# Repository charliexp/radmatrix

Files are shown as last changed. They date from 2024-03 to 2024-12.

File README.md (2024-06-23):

# radmatrix

Smol modular LED matrix, consisting of 3 types of 50x50mm modules:

- LED modules with a 20x20 matrix of 0603 red LEDs
- Driver modules at the end of rows and columns (bottom and right)
- Microcontroller (RP2040) board in the bottom-right corner

This was built as my first "serious" electronics project and its main purpose was to learn electronics a bit better. Some RP2040 embedded knowledge and a blinky lights object are nice side effects.

## Results

TODO: Photos, video, PCB renders

## Design details

The LED matrix and driver module PCB design were optimized for JLCPCB Assembly - i.e. only using parts available in its (LCSC) catalog and strongly preferring Basic parts to avoid paying feeder fees. The LEDs chosen were the cheapest available in JLC's catalog (they work fine btw).

The microcontroller board was optimized for JLC PCBA to a lesser extent -- I used multiple parts that would incur a feeder fee if not for the fact that I hand-soldered them.

The display is capable of:

- 8 bit red color
- 60fps (TODO, 30fps demonstrated)

Additionally, the MCU board can:

- Read multiple "videos" (specially encoded for this firmware) from an SD card
- Pipe in 8-bit 44kHz audio
- Transmit and receive CAN messages

## v2

Now that I've leraned from my mistakes, here's what I would do if I were to build a v2 of this display (I probably won't):

- Use square, preferably RGB LED "pixels"
- Fit them in a grid of **standard** spacing (i.e. 1, 1.27, 2, or 2.54mm)
- Put pixels edge to edge
  - Current design simplfiied connections and JLC assembly, but it's ugly
- Use a black PCB for the LED matrix for increased contrast
- Move driver modules from column/row ends to the backs of LED modules
  - The current design is kinda neat, but it doesn't scale, as with each additional row of modules, the perceptual brightness of LEDs goes down
- A 2mm-spacing 32x32 standard module seems reasonable
- Connection between LED module and driver module would be done by placing 1x16 SMD pin headers alongside corners (split in half, say, bottom-left and top-right for rows, and likewise for columns to allow edge-to-edge clearance)
  - Possibly some additional pin headers for added stability, maybe some solderable nuts - some mechanical connection between modules would be nice
- Driver modules
  - Would consider constant-current drivers, although resistor-based approach seems to work fine and appeared cheaper
  - If resistor-based approach is still used, I would consider a buck converter for creating a variable LED power supply
  - Would consider not skipping any of the shift register stages as that makes programming more annoying, and in this approach, it shouldn't make layout too difficult
  - Fix v1 bugs of course
  - Would consider faster shift registers. Perhaps 74HCT (5V supply to '595 gives best performance, and HCT can handle 3v3 input), or LV*
  - Would consider a decoder instead of shift registers for selecting rows. The current method is risky in that if programming is not done correctly, multiple LED rows could be lighting up at the same time (with one resistor for multiple LEDs), overstressing them. It's likely that current approach is cheaper and requires fewer signal lines though
- Driving the display
  - Each LED/driver module would have a separate connection to the MCU board - sharing row selection, OE, SRCLK, RCLK, lines, but each having its own SER line
  - With PIO, this would have minimal impact on driving performance, and RP2040 IO counts would likely allow for 16-20 module to be connected to a single MCU board
  - This could in principle be extended further with multiple MCU boards talking to a master
  - The display would become /32, so would be brighter and that would not depend on its height
  - Each driver module should have a buffer before/after it to improve the signal

Note that while most people do projects like this with an FPGA, in my opinion the RP2040, thanks to PIO, is more than capable enough for this job at a better price, and can do other stuff in addition to just driving the display. The main downside vs an FPGA is limited IO (30 pins), which limits how big of a display can be driven. With the design above, likely ~20kpx (though this could be optimized further)

Noting the above so I don't forget or in case someone else wants to take this project further. To me, this project has fulfilled its educational goal, and making large LED displays this way is impractical given that you can get HUB75 modules for less than just the LED cost off LCSC.

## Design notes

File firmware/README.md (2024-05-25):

## convert video

automatically:

```sh
scripts/convert.sh ../badapple.webm
```

the output is in video_output

or manually:

```
ffmpeg -i ../badapple.webm -vf "fps=30,scale=40:40:force_original_aspect_ratio=increase,crop=40:40,format=gray" gfx/frame_%04d.png
```

move to `gfx` folder, then:

```
# old method
# python3 scripts/gfx_convert.py
python3 scripts/gfx_to_blob.py
```

convert audio

```
ffmpeg -i ../badapple.webm -ar 44000 audio/output.wav
```

move to `audio` folder, then:

```
python3 scripts/audio_convert.py
```

## play videos on device

create `video/YOURNAME/` folder, with files:

(where files are audio.bin, gfx.bin, gfx_len.bin)

NOTE: yourname MUST be at most 8 characters long

also `video/playlist.txt` with names of videos in order

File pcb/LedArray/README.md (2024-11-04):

# LED Matrix module

50x50mm module with 20x20 LED matrix

## Errata

### Rev A

1. I'm an idiot and somehow managed to switch polarity of LEDs. Rows were supposed to be cathodes, and columns anodes, but it's the other way around. Fixable by a 90° rotation, albeit with less than ideal trace layout. Oh well.
2. The notes about the XL-1608SURC-06 LED are incorrect, and were in fact taken from XL-1608SURC-04's data sheet. (Correction: It seems that the ealier version of XL-1608SURC-06 datasheet was incorrect). The correct info is:
   - Forward voltage: 1.9-2.3V (at 20mA)
   - Max peak forward current: 80mA
   - Max continuous forward current: 20mA

### Rev B

Sent for manufacturing 2024-11-04 (est.), delivered TBD.

Fixed orientation (with an unideal trace layout) and notes on the back.

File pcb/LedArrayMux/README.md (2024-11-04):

# LED Multiplexer

50x50mm module for driving rows and columns of LED Matrix modules

## Revisions

### Rev A

Manufactured 2024-04-06, delivered 2024-04-13.

Errata:

1. PMOS gates are pulled up to VLED (5V), while the shift register is powered from 3V3 and signals above VCC are not allowed. Ouch!
   - NMOS gates (i.e. row drivers) are not affected
   - This is not easily fixable on the board itself
   - It doesn't appear that 74HC595 dies immediately because of this, and the 10k resistor would limit worst-case scenario current to 0.5mA, but probably bad idea to ignore this altogether
   - It's possible to set VCC to 5V, and add level shifting on signal lines
   - Alternatively, the shift register could be replaced with 74HCT595 so that 3V3 signals register as logic high at 5V VCC

### Rev B

Ordered for manufacturing 2024-11-04 (est.), delivered TBD

Minor layout tweaks + added more decoupling capacitance. The major bugs are not fixed, as this rev is for a display that has it worked around.

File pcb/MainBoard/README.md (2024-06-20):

# Main Board

50x50mm microcontroller module, driving LedArrayMux modules. Contains an RP2040 microcontroller, a CAN transceiver, PWM audio output, current sensing, and level shifters to work around LedArrayMux bugs.

## Revisions

### Rev A

Errata:

1. Level shifters are too slow to be useful
  - Workaround: decrease pullup values to obnoxiously low ones (100-180Ω); do not use level shifters; increase PIO delays until functional
2. CAN receive signal is not level shifted, which exposes RP2040 to a 5V signal
  - Workaround: Do nothing; replace with a 3v3 CAN transceiver
3. The 431 shunt voltage reference does not work correctly
  - Workaround: use main 3v3 regulator for vref
4. PWM audio signal filter is suspected to be responsible for poor quality audio

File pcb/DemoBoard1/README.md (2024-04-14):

# Demo Board 1

Learning how to use shift registers, darlington arrays, and mosfets. I don't know what I'm doing.

Demo board containing LED Matrix module + some of the above components for hands-on experimentation.

Ordered 2024-03-05, manufactured, then delivered 2024-03-22.

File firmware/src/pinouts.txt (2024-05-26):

## SD breadboard connector

                  17
DAT1   GND  +3V3   CS     SHLD
  2     4     6     8     10
  1     3     5     7     9
DET   MISO   CLK   MOSI   DAT2
28     16    18     19

## Big SD card

D2  D3/CS   CMD/MOSI   VSS1 VDD CLK  VSS2  D0/MISO  D1
x    17        19       x    x   18   x      16     x

## LED drivers

- VCC
- SER
- OE
- RCLK
- SRCLK
- SRCLR

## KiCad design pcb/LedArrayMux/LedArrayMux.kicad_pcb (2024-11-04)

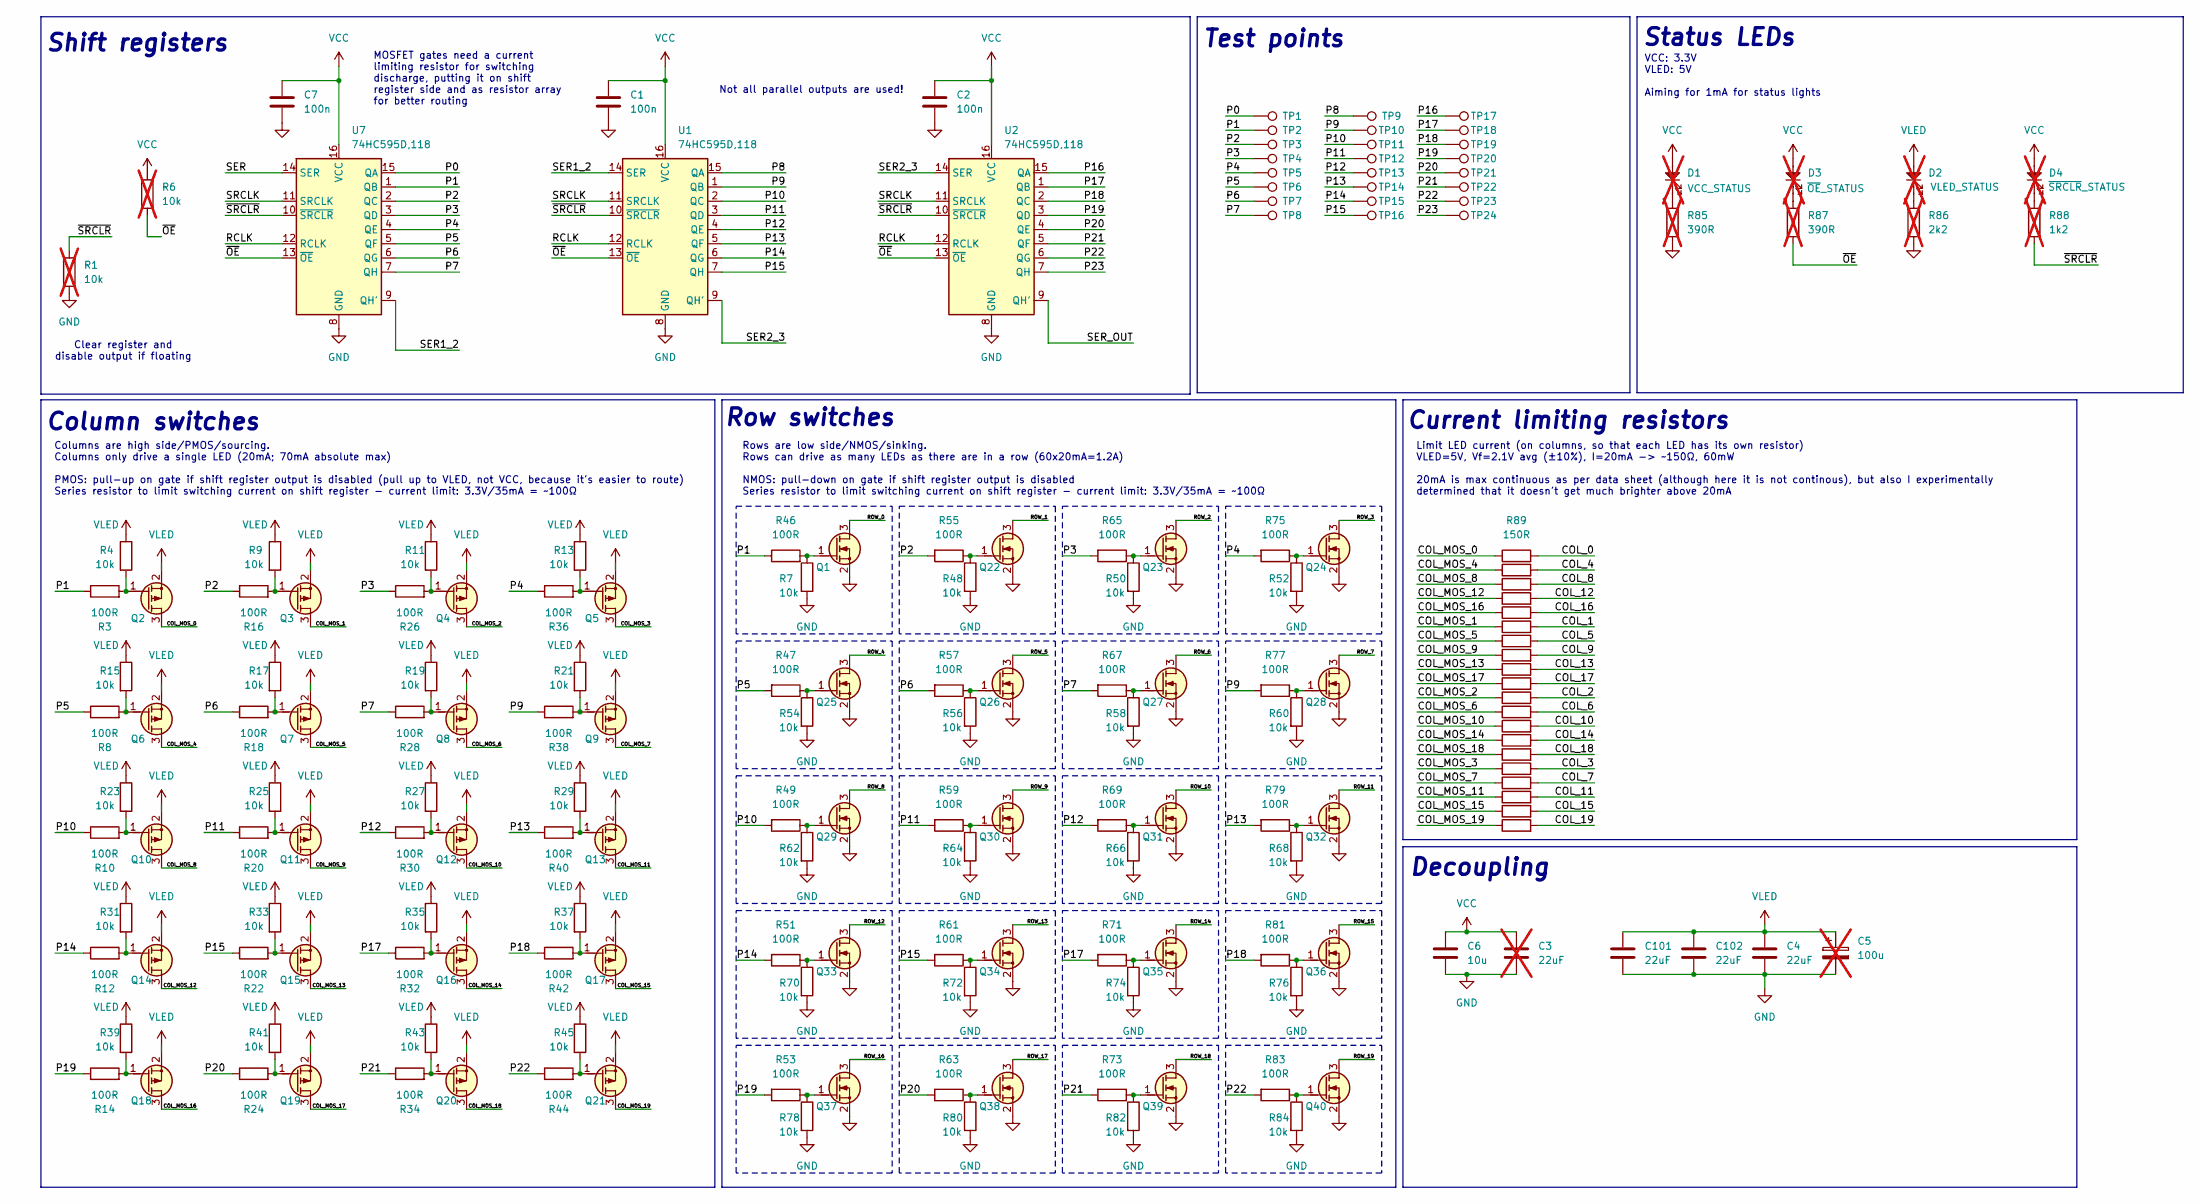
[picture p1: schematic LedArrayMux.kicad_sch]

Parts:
C1, C2, C7: 100n; R_0402_1005Metric; LCSC C307331
C3: 22uF; C_1206_3216Metric; LCSC C12891; not fitted
C4, C101, C102: 22uF; C_1206_3216Metric; LCSC C12891
C5: 100u; CP_EIA-3528-15_AVX-H; LCSC C16133; not fitted
C6: 10u; C_0603_1608Metric; LCSC C96446
D1, D2, D3: KT-0805G; LED_0805_2012Metric; LCSC C2297; not fitted
D4: KT-0805Y; LED_0805_2012Metric; LCSC C2296; not fitted
Q1, Q22, Q23, Q24, Q25, Q26, Q27, Q28, Q29, Q30, Q31, Q32, Q33, Q34, Q35, Q36, Q37, Q38, Q39, Q40: HL2304; SOT-23; LCSC C7420346
Q2, Q3, Q4, Q5, Q6, Q7, Q8, Q9, Q10, Q11, Q12, Q13, Q14, Q15, Q16, Q17, Q18, Q19, Q20, Q21: HL2301A; SOT-23; LCSC C7420344
R1, R6: 10k; R_0402_1005Metric; LCSC C25744; not fitted
R3, R8, R10, R12, R14, R16, R18, R20, R22, R24, R26, R28, R30, R32, R34, R36, R38, R40, R42, R44, R46, R47, R49, R51, R53, R55, R57, R59, R61, R63, R65, R67, R69, R71, R73, R75, R77, R79, R81, R83: 100R; R_0402_1005Metric
R4, R7, R9, R11, R13, R15, R17, R19, R21, R23, R25, R27, R29, R31, R33, R35, R37, R39, R41, R43, R45, R48, R50, R52, R54, R56, R58, R60, R62, R64, R66, R68, R70, R72, R74, R76, R78, R80, R82, R84: 10k; R_0402_1005Metric; LCSC C25744
R85, R87: 390R; R_0603_1608Metric; not fitted
R86: 2k2; R_0603_1608Metric; not fitted
R88: 1k2; R_0603_1608Metric; not fitted
R89, R90, R91, R92, R93, R94, R95, R96, R97, R98, R99, R100, R101, R102, R103, R104, R105, R106, R107, R108: 150R; R_0805_2012Metric
TP1, TP2, TP3, TP4, TP5, TP6, TP7, TP8, TP9, TP10, TP11, TP12, TP13, TP14, TP15, TP16, TP17, TP18, TP19, TP20, TP21, TP22, TP23, TP24: TestPoint; TestPoint_Pad_D1.0mm
U1, U2, U7: 74HC595D,118; SO-16_3.9x9.9mm_P1.27mm; LCSC C5947

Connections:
/COL_0: R89.2
/COL_1: R94.2
/COL_2: R99.2
/COL_3: R104.2
/COL_4: R90.2
/COL_5: R95.2
/COL_6: R100.2
/COL_7: R105.2
/COL_8: R91.2
/COL_9: R96.2
/COL_10: R101.2
/COL_11: R106.2
/COL_12: R92.2
/COL_13: R97.2
/COL_14: R102.2
/COL_15: R107.2
/COL_16: R93.2
/COL_17: R98.2
/COL_18: R103.2
/COL_19: R108.2
/COL_MOS_0: Q2.3 (D), R89.1
/COL_MOS_1: Q3.3 (D), R94.1
/COL_MOS_2: Q4.3 (D), R99.1
/COL_MOS_3: Q5.3 (D), R104.1
/COL_MOS_4: Q6.3 (D), R90.1
/COL_MOS_5: Q7.3 (D), R95.1
/COL_MOS_6: Q8.3 (D), R100.1
/COL_MOS_7: Q9.3 (D), R105.1
/COL_MOS_8: Q10.3 (D), R91.1
/COL_MOS_9: Q11.3 (D), R96.1
/COL_MOS_10: Q12.3 (D), R101.1
/COL_MOS_11: Q13.3 (D), R106.1
/COL_MOS_12: Q14.3 (D), R92.1
/COL_MOS_13: Q15.3 (D), R97.1
/COL_MOS_14: Q16.3 (D), R102.1
/COL_MOS_15: Q17.3 (D), R107.1
/COL_MOS_16: Q18.3 (D), R93.1
/COL_MOS_17: Q19.3 (D), R98.1
/COL_MOS_18: Q20.3 (D), R103.1
/COL_MOS_19: Q21.3 (D), R108.1
/P0: TP1.1, U7.15 (QA)
/P1: R3.1, R46.1, TP2.1, U7.1 (QB)
/P2: R16.1, R55.2, TP3.1, U7.2 (QC)
/P3: R26.1, R65.2, TP4.1, U7.3 (QD)
/P4: R36.1, R75.2, TP5.1, U7.4 (QE)
/P5: R8.1, R47.2, TP6.1, U7.5 (QF)
/P6: R18.1, R57.2, TP7.1, U7.6 (QG)
/P7: R28.1, R67.2, TP8.1, U7.7 (QH)
/P8: TP9.1, U1.15 (QA)
/P9: R38.1, R77.2, TP10.1, U1.1 (QB)
/P10: R10.1, R49.2, TP11.1, U1.2 (QC)
/P11: R20.1, R59.2, TP12.1, U1.3 (QD)
/P12: R30.1, R69.2, TP13.1, U1.4 (QE)
/P13: R40.1, R79.2, TP14.1, U1.5 (QF)
/P14: R12.1, R51.2, TP15.1, U1.6 (QG)
/P15: R22.1, R61.2, TP16.1, U1.7 (QH)
/P16: TP17.1, U2.15 (QA)
/P17: R32.1, R71.2, TP18.1, U2.1 (QB)
/P18: R42.1, R81.2, TP19.1, U2.2 (QC)
/P19: R14.1, R53.2, TP20.1, U2.3 (QD)
/P20: R24.1, R63.2, TP21.1, U2.4 (QE)
/P21: R34.1, R73.2, TP22.1, U2.5 (QF)
/P22: R44.1, R83.2, TP23.1, U2.6 (QG)
/P23: TP24.1, U2.7 (QH)
/RCLK: U1.12 (RCLK), U2.12 (RCLK), U7.12 (RCLK)
/ROW_0: Q1.3 (D)
/ROW_1: Q22.3 (D)
/ROW_2: Q23.3 (D)
/ROW_3: Q24.3 (D)
/ROW_4: Q25.3 (D)
/ROW_5: Q26.3 (D)
/ROW_6: Q27.3 (D)
/ROW_7: Q28.3 (D)
/ROW_8: Q29.3 (D)
/ROW_9: Q30.3 (D)
/ROW_10: Q31.3 (D)
/ROW_11: Q32.3 (D)
/ROW_12: Q33.3 (D)
/ROW_13: Q34.3 (D)
/ROW_14: Q35.3 (D)
/ROW_15: Q36.3 (D)
/ROW_16: Q37.3 (D)
/ROW_17: Q38.3 (D)
/ROW_18: Q39.3 (D)
/ROW_19: Q40.3 (D)
/SER: U7.14 (SER)
/SER1_2: U1.14 (SER), U7.9 (QH')
/SER2_3: U1.9 (QH'), U2.14 (SER)
/SER_OUT: U2.9 (QH')
/SRCLK: U1.11 (SRCLK), U2.11 (SRCLK), U7.11 (SRCLK)
/~OE: R6.2, R87.2, U1.13 (~OE), U2.13 (~OE), U7.13 (~OE)
/~SRCLR: R1.1, R88.2, U1.10 (~SRCLR), U2.10 (~SRCLR), U7.10 (~SRCLR)
GND: C1.2, C2.2, C3.2, C4.2, C5.2, C6.2, C7.2, C101.2, C102.2, Q1.2 (S), Q22.2 (S), Q23.2 (S), Q24.2 (S), Q25.2 (S), Q26.2 (S), Q27.2 (S), Q28.2 (S), Q29.2 (S), Q30.2 (S), Q31.2 (S), Q32.2 (S), Q33.2 (S), Q34.2 (S), Q35.2 (S), Q36.2 (S), Q37.2 (S), Q38.2 (S), Q39.2 (S), Q40.2 (S), R1.2, R7.2, R48.2, R50.2, R52.2, R54.2, R56.2, R58.2, R60.2, R62.2, R64.2, R66.2, R68.2, R70.2, R72.2, R74.2, R76.2, R78.2, R80.2, R82.2, R84.2, R85.2, R86.2, U1.8 (GND), U2.8 (GND), U7.8 (GND)
unnamed: D1.1, R85.1
unnamed: D2.1, R86.1
unnamed: D3.1, R87.1
unnamed: D4.1, R88.1
unnamed: Q1.1 (G), R7.1, R46.2
unnamed: Q2.1 (G), R3.2, R4.2
unnamed: Q3.1 (G), R9.2, R16.2
unnamed: Q4.1 (G), R11.2, R26.2
unnamed: Q5.1 (G), R13.2, R36.2
unnamed: Q6.1 (G), R8.2, R15.2
unnamed: Q7.1 (G), R17.2, R18.2
unnamed: Q8.1 (G), R19.2, R28.2
unnamed: Q9.1 (G), R21.2, R38.2
unnamed: Q10.1 (G), R10.2, R23.2
unnamed: Q11.1 (G), R20.2, R25.2
unnamed: Q12.1 (G), R27.2, R30.2
unnamed: Q13.1 (G), R29.2, R40.2
unnamed: Q14.1 (G), R12.2, R31.2
unnamed: Q15.1 (G), R22.2, R33.2
unnamed: Q16.1 (G), R32.2, R35.2
unnamed: Q17.1 (G), R37.2, R42.2
unnamed: Q18.1 (G), R14.2, R39.2
unnamed: Q19.1 (G), R24.2, R41.2
unnamed: Q20.1 (G), R34.2, R43.2
unnamed: Q21.1 (G), R44.2, R45.2
unnamed: Q22.1 (G), R48.1, R55.1
unnamed: Q23.1 (G), R50.1, R65.1
unnamed: Q24.1 (G), R52.1, R75.1
unnamed: Q25.1 (G), R47.1, R54.1
unnamed: Q26.1 (G), R56.1, R57.1
unnamed: Q27.1 (G), R58.1, R67.1
unnamed: Q28.1 (G), R60.1, R77.1
unnamed: Q29.1 (G), R49.1, R62.1
unnamed: Q30.1 (G), R59.1, R64.1
unnamed: Q31.1 (G), R66.1, R69.1
unnamed: Q32.1 (G), R68.1, R79.1
unnamed: Q33.1 (G), R51.1, R70.1
unnamed: Q34.1 (G), R61.1, R72.1
unnamed: Q35.1 (G), R71.1, R74.1
unnamed: Q36.1 (G), R76.1, R81.1
unnamed: Q37.1 (G), R53.1, R78.1
unnamed: Q38.1 (G), R63.1, R80.1
unnamed: Q39.1 (G), R73.1, R82.1
unnamed: Q40.1 (G), R83.1, R84.1
VCC: C1.1, C2.1, C3.1, C6.1, C7.1, D1.2, D3.2, D4.2, R6.1, U1.16 (VCC), U2.16 (VCC), U7.16 (VCC)
VLED: C4.1, C5.1, C101.1, C102.1, D2.2, Q2.2 (S), Q3.2 (S), Q4.2 (S), Q5.2 (S), Q6.2 (S), Q7.2 (S), Q8.2 (S), Q9.2 (S), Q10.2 (S), Q11.2 (S), Q12.2 (S), Q13.2 (S), Q14.2 (S), Q15.2 (S), Q16.2 (S), Q17.2 (S), Q18.2 (S), Q19.2 (S), Q20.2 (S), Q21.2 (S), R4.1, R9.1, R11.1, R13.1, R15.1, R17.1, R19.1, R21.1, R23.1, R25.1, R27.1, R29.1, R31.1, R33.1, R35.1, R37.1, R39.1, R41.1, R43.1, R45.1

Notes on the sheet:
Rows are low side/NMOS/sinking. Rows can drive as many LEDs as there are in a row (60x20mA=1.2A) NMOS: pull-down on gate if shift register output is disabled Series resistor to limit switching current on shift register - current limit: 3.3V/35mA = ~100Ω
Columns are high side/PMOS/sourcing. Columns only drive a single LED (20mA; 70mA absolute max) PMOS: pull-up on gate if shift register output is disabled (pull up to VLED, not VCC, because it's easier to route) Series resistor to limit switching current on shift register - current limit: 3.3V/35mA 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
Limit LED current (on columns, so that each LED has its own resistor) VLED=5V, Vf=2.1V avg (±10%), I=20mA -> ~150Ω, 60mW 20mA is max continuous as per data sheet (although here it is not continous), but also I experimentally determined that it doesn't get much brighter above 20mA
MOSFET gates need a current limiting resistor for switching discharge, putting it on shift register side and as resistor array for better routing
Not all parallel outputs are used!
Test points
Shift registers
Row switches
Status LEDs
Decoupling
VCC: 3.3V VLED: 5V Aiming for 1mA for status lights
Current limiting resistors
Column switches
Clear register and disable output if floating

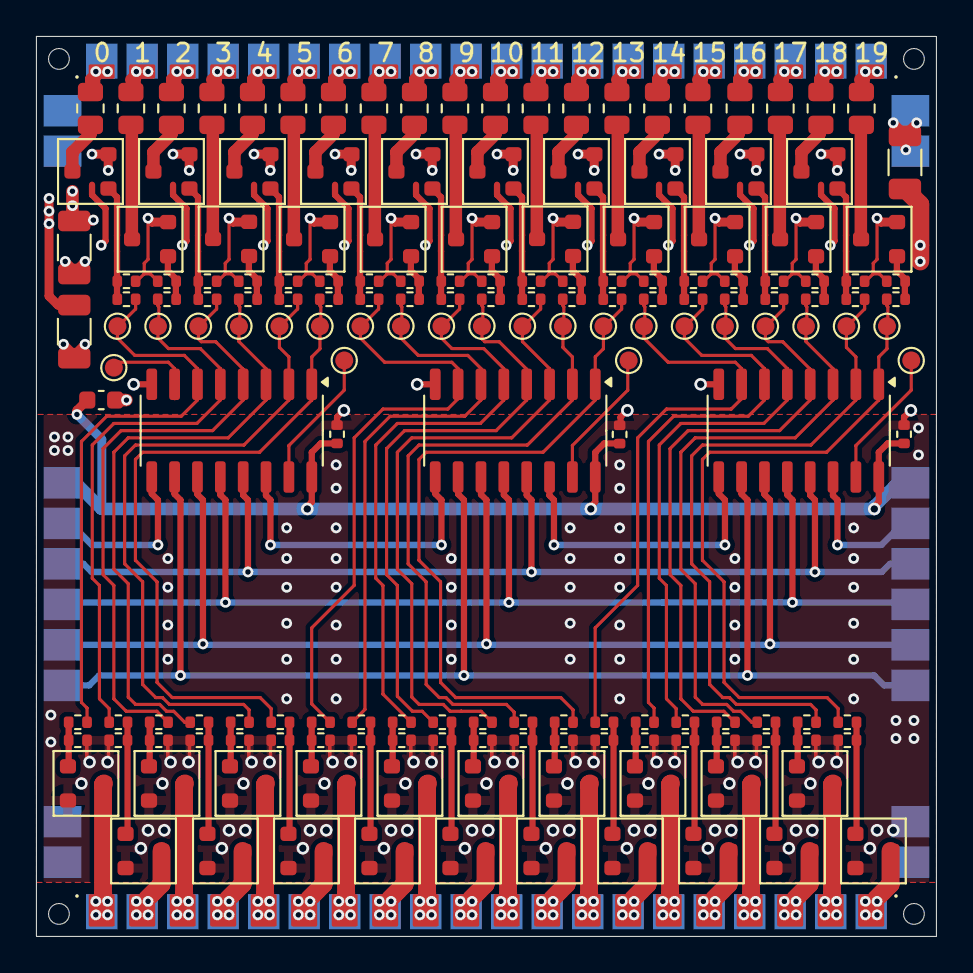
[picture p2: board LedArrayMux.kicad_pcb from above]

Board: 2 copper layers, 50.0 x 50.0 mm, 174 parts (0 on the bottom side), 93 nets.

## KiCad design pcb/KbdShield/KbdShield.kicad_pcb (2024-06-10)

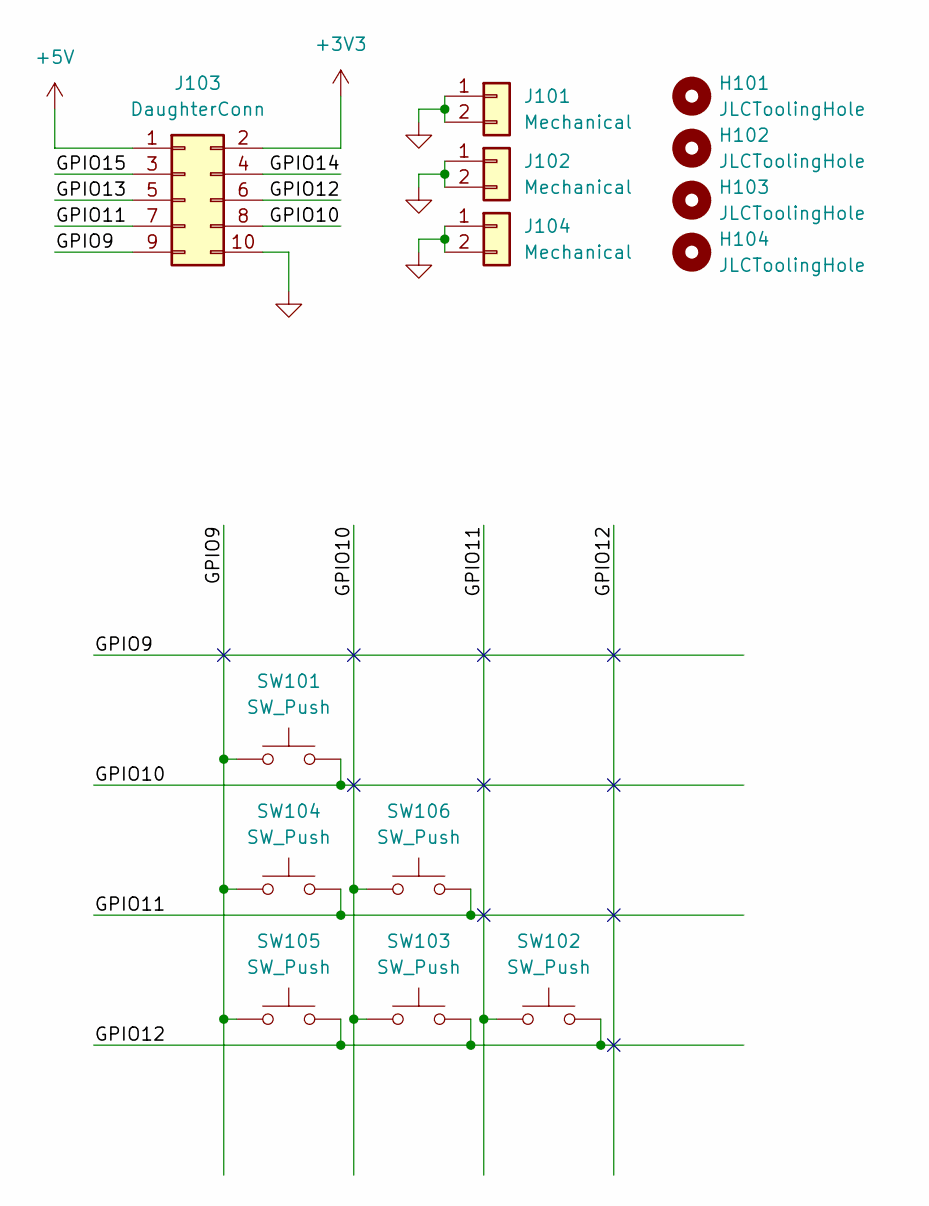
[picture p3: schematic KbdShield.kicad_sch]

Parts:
H101, H102, H103, H104: JLCToolingHole; jlcpcb-tooling-hole
J101, J102, J104: Mechanical; PinHeader_1x02_P2.54mm_Vertical
J103: DaughterConn; PinSocket_2x05_P2.54mm_Vertical
SW101, SW102, SW103, SW104, SW105, SW106: SW_Push; SW_Push_1P1T_NO_CK_KSC6xxJ

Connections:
+3V3: J103.2
+5V: J103.1
/GPIO9: J103.9, SW101.1, SW104.1, SW105.1
/GPIO10: J103.8, SW101.2, SW103.1, SW106.1
/GPIO11: J103.7, SW102.1, SW104.2, SW106.2
/GPIO12: J103.6, SW102.2, SW103.2, SW105.2
/GPIO13: J103.5
/GPIO14: J103.4
/GPIO15: J103.3
GND: J101.1, J101.2, J102.1, J102.2, J103.10, J104.1, J104.2

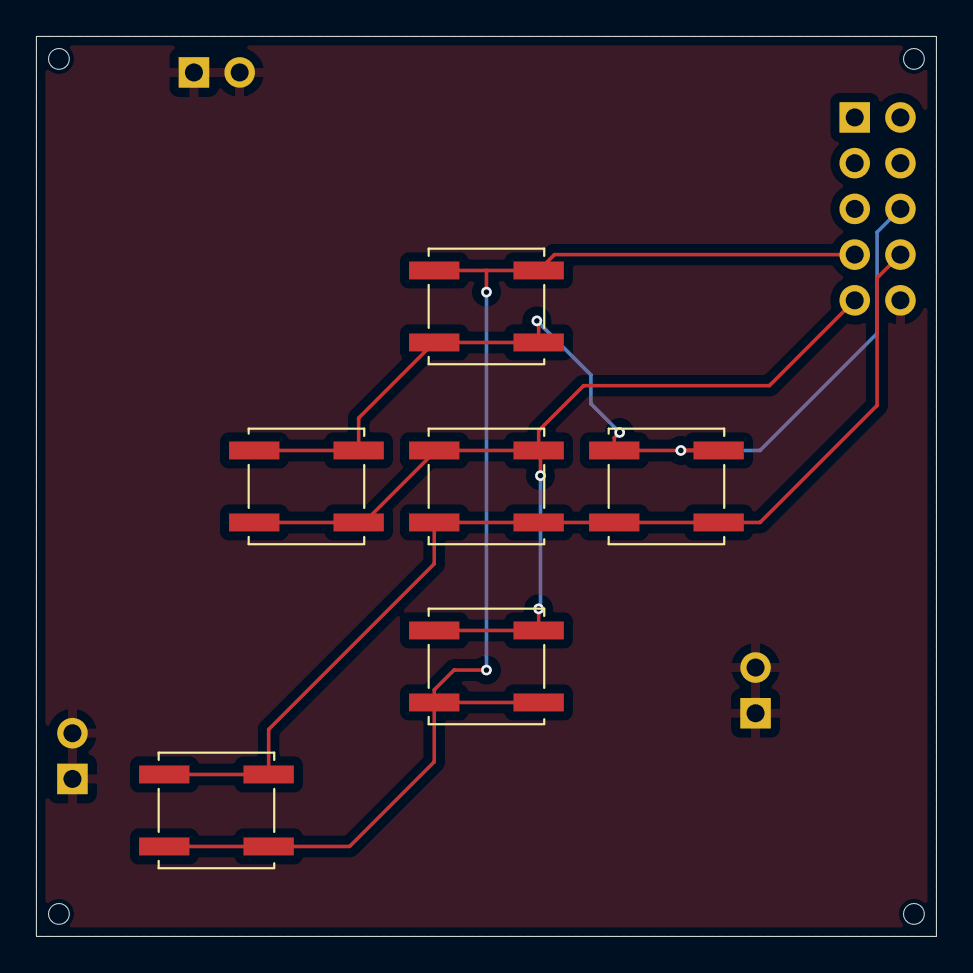
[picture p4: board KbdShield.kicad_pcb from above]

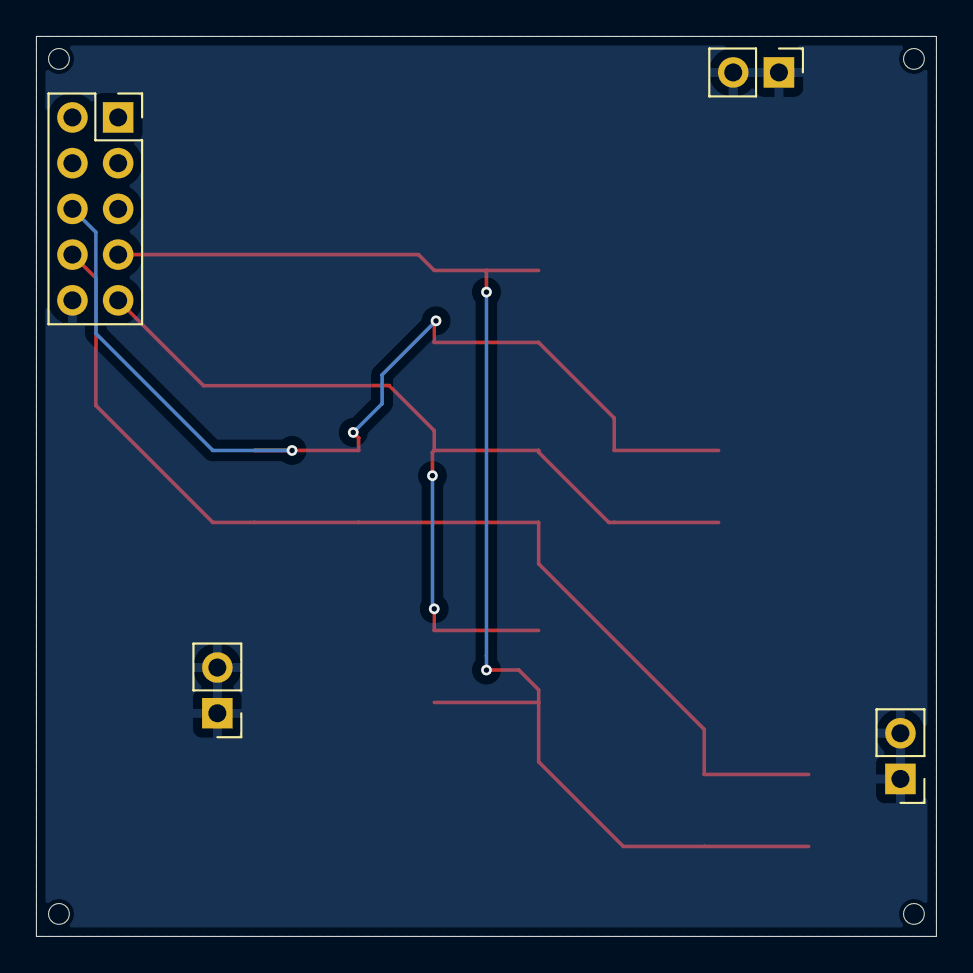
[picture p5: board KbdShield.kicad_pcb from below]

Board: 2 copper layers, 50.0 x 50.0 mm, 14 parts (4 on the bottom side), 5 nets.

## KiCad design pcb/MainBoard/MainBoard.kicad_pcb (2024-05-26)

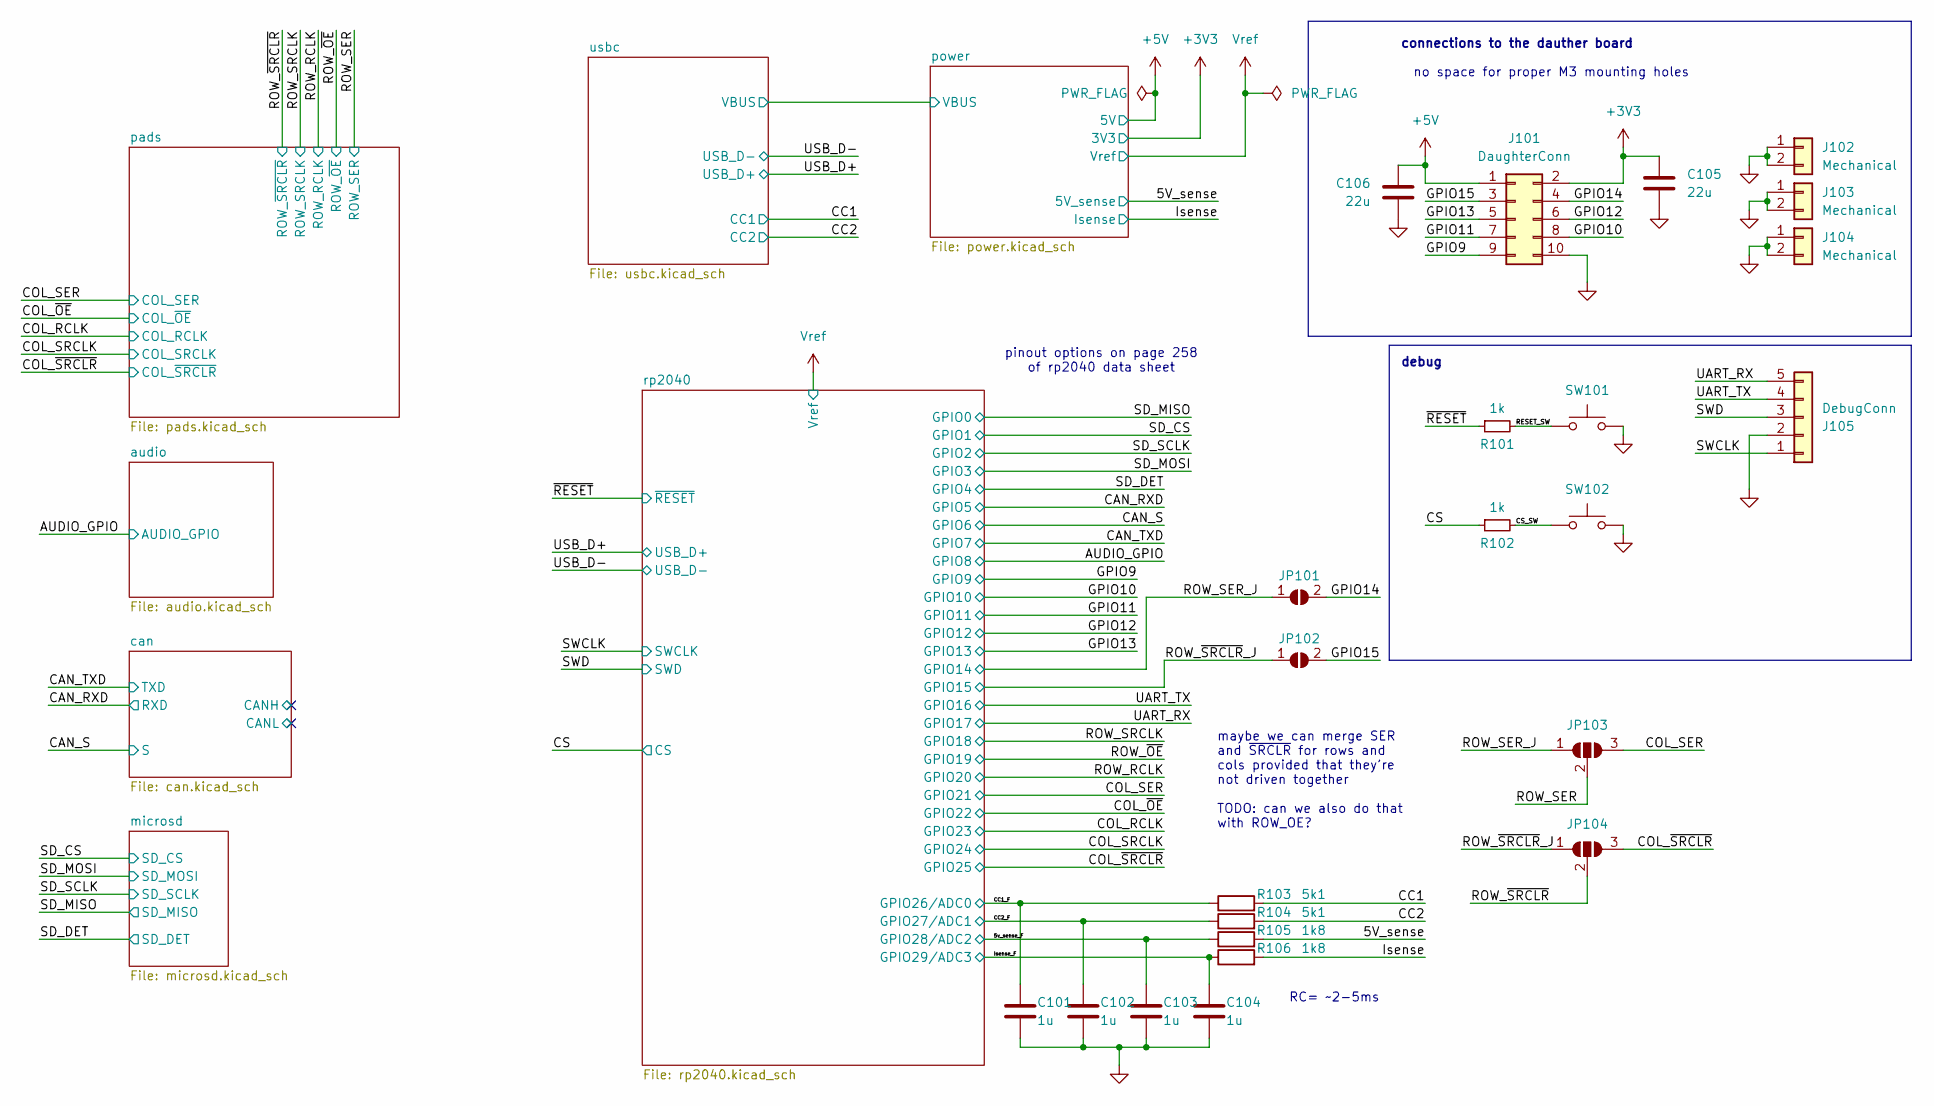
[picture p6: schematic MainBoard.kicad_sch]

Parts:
C101, C102, C103, C104: 1u; C_0402_1005Metric; LCSC C52923
C105, C106: 22u; C_0805_2012Metric; LCSC C45783
J101: DaughterConn; PinHeader_2x05_P2.54mm_Vertical
J102, J103, J104: Mechanical; PinHeader_1x02_P2.54mm_Vertical
J105: DebugConn; PinSocket_1x05_P2.54mm_Horizontal
JP101, JP102: SolderJumper_2_Open; SolderJumper-2_Open_RoundedPad_Smol
JP103, JP104: SolderJumper_3_Open; SolderJumper-3_Open_RoundedPad_Smol
R101, R102: 1k; R_0402_1005Metric; LCSC C11702
R103, R104: 5k1; R_0402_1005Metric; LCSC C25905
R105, R106: 1k8; R_0603_1608Metric; LCSC C4177
SW101, SW102: SW; HY-C-03

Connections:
+3V3: C105.1, J101.2; also elsewhere on the board
+5V: C106.1, J101.1; also elsewhere on the board
/5V_sense: R105.2; also elsewhere on the board
/5v_sense_F: C103.1, R105.1; also elsewhere on the board
/CC1: R103.2; also elsewhere on the board
/CC1_F: C101.1, R103.1; also elsewhere on the board
/CC2: R104.2; also elsewhere on the board
/CC2_F: C102.1, R104.1; also elsewhere on the board
/COL_SER: JP103.3 (B); also elsewhere on the board
/COL_~SRCLR: JP104.3 (B); also elsewhere on the board
/CS: R102.1; also elsewhere on the board
/CS_SW: R102.2, SW102.2
/GPIO9: J101.9; also elsewhere on the board
/GPIO10: J101.8; also elsewhere on the board
/GPIO11: J101.7; also elsewhere on the board
/GPIO12: J101.6; also elsewhere on the board
/GPIO13: J101.5; also elsewhere on the board
/GPIO14: J101.4, JP101.2 (B)
/GPIO15: J101.3, JP102.2 (B)
/Isense: R106.2; also elsewhere on the board
/Isense_F: C104.1, R106.1; also elsewhere on the board
/RESET_SW: R101.2, SW101.2
/ROW_SER: JP103.2 (C); also elsewhere on the board
/ROW_SER_J: JP101.1 (A), JP103.1 (A); also elsewhere on the board
/ROW_~SRCLR: JP104.2 (C); also elsewhere on the board
/ROW_~SRCLR_J: JP102.1 (A), JP104.1 (A); also elsewhere on the board
/SWCLK: J105.1; also elsewhere on the board
/SWD: J105.3; also elsewhere on the board
/UART_RX: J105.5; also elsewhere on the board
/UART_TX: J105.4; also elsewhere on the board
/~RESET: R101.1; also elsewhere on the board
GND: C101.2, C102.2, C103.2, C104.2, C105.2, C106.2, J101.10, J102.1, J102.2, J103.1, J103.2, J104.1, J104.2, J105.2, SW101.1, SW102.1; also elsewhere on the board

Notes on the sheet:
RC= ~2-5ms
maybe we can merge SER and ~{SRCLR} for rows and cols provided that they're not driven together TODO: can we also do that with ROW_OE?
pinout options on page 258 of rp2040 data sheet
connections to the dauther board
no space for proper M3 mounting holes
debug

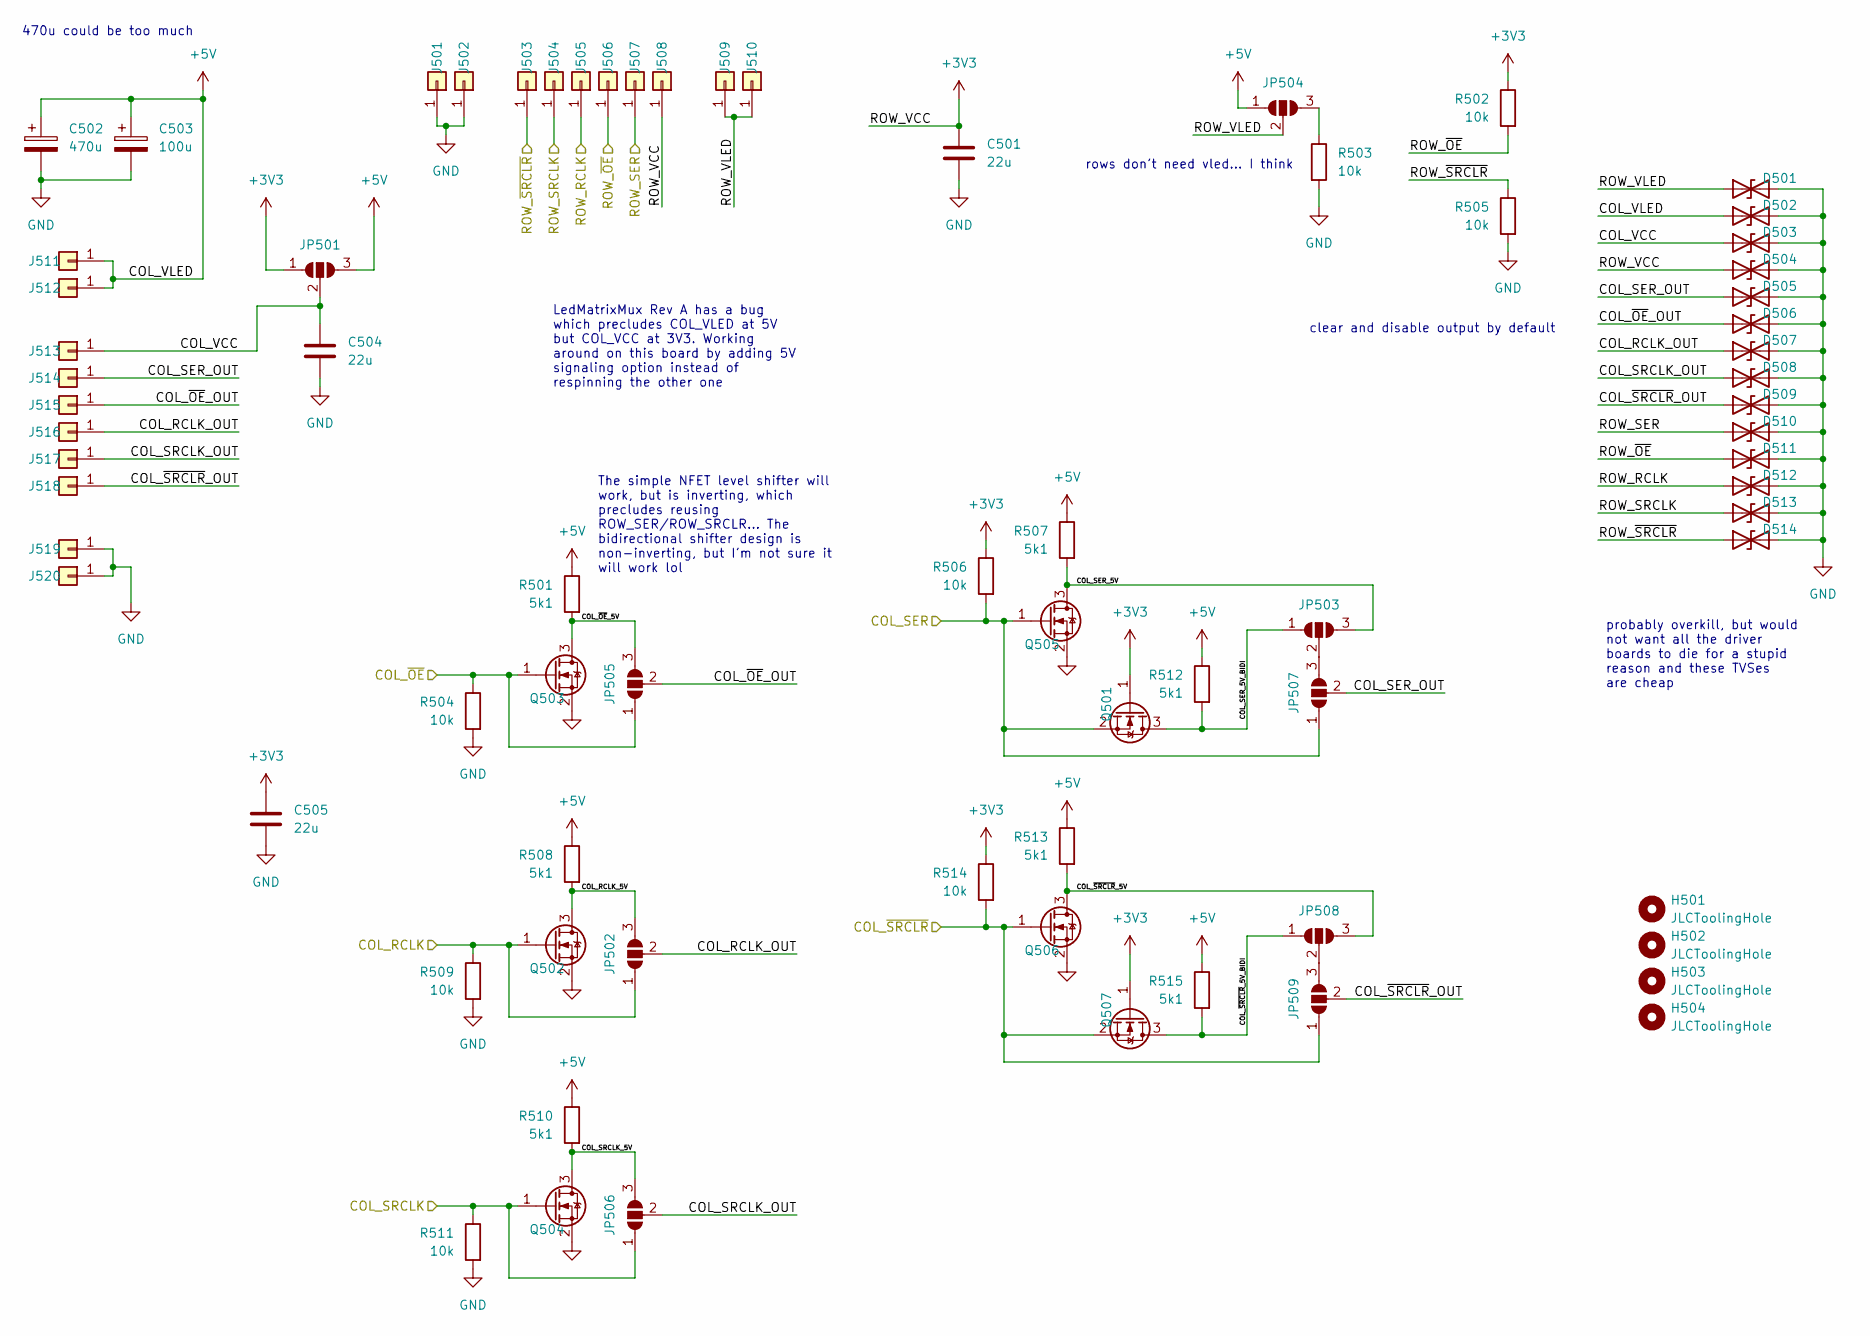
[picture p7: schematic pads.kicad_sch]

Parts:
C501, C504, C505: 22u; C_0805_2012Metric; LCSC C45783
C502: 470u; CP_Elec_8x10.5
C503: 100u; CP_EIA-3528-15_AVX-H; LCSC C16133
D501, D502, D503, D504, D505, D506, D507, D508, D509, D510, D511, D512, D513, D514: H5VL10B; DFN1006_TVS; LCSC C7420372
H501, H502, H503, H504: JLCToolingHole; jlcpcb-tooling-hole
J501, J502, J503, J504, J505, J506, J507, J508, J509, J510, J511, J512, J513, J514, J515, J516, J517, J518, J519, J520: Conn_01x01; solder-pad-2.25mm
JP501, JP502, JP503, JP504, JP505, JP506, JP507, JP508, JP509: SolderJumper_3_Open; SolderJumper-3_Open_RoundedPad_Smol
Q501, Q502, Q503, Q504, Q505, Q506, Q507: HL2304; SOT-23; LCSC C7420346
R501, R507, R508, R510, R512, R513, R515: 5k1; R_0402_1005Metric; LCSC C25905
R502, R503, R504, R505, R506, R509, R511, R514: 10k; R_0402_1005Metric; LCSC C25744

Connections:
+3V3: C501.1, C505.1, D504.1 (A1), J508.1, JP501.1 (A), Q501.1 (G), Q507.1 (G), R502.1, R506.1, R514.1; also elsewhere on the board
+5V: C502.1, C503.1, D502.1 (A1), J511.1, J512.1, JP501.3 (B), JP504.1 (A), R501.1, R507.1, R508.1, R510.1, R512.1, R513.1, R515.1; also elsewhere on the board
/COL_RCLK: JP502.1 (A), Q502.1 (G), R509.1; also elsewhere on the board
/COL_SER: JP507.1 (A), Q501.2 (S), Q505.1 (G), R506.2; also elsewhere on the board
/COL_SRCLK: JP506.1 (A), Q504.1 (G), R511.1; also elsewhere on the board
/COL_~OE: JP505.1 (A), Q503.1 (G), R504.1; also elsewhere on the board
/COL_~SRCLR: JP509.1 (A), Q506.1 (G), Q507.2 (S), R514.2; also elsewhere on the board
/ROW_RCLK: D512.1 (A1), J505.1; also elsewhere on the board
/ROW_SER: D510.1 (A1), J507.1; also elsewhere on the board
/ROW_SRCLK: D513.1 (A1), J504.1; also elsewhere on the board
/ROW_~OE: D511.1 (A1), J506.1, R502.2; also elsewhere on the board
/ROW_~SRCLR: D514.1 (A1), J503.1, R505.1; also elsewhere on the board
/pads/COL_RCLK_5V: JP502.3 (B), Q502.3 (D), R508.2
/pads/COL_RCLK_OUT: D507.1 (A1), J516.1, JP502.2 (C)
/pads/COL_SER_5V: JP503.3 (B), Q505.3 (D), R507.2
/pads/COL_SER_5V_BIDI: JP503.1 (A), Q501.3 (D), R512.2
/pads/COL_SER_OUT: D505.1 (A1), J514.1, JP507.2 (C)
/pads/COL_SRCLK_5V: JP506.3 (B), Q504.3 (D), R510.2
/pads/COL_SRCLK_OUT: D508.1 (A1), J517.1, JP506.2 (C)
/pads/COL_VCC: C504.1, D503.1 (A1), J513.1, JP501.2 (C)
/pads/COL_~OE_5V: JP505.3 (B), Q503.3 (D), R501.2
/pads/COL_~OE_OUT: D506.1 (A1), J515.1, JP505.2 (C)
/pads/COL_~SRCLR_5V: JP508.3 (B), Q506.3 (D), R513.2
/pads/COL_~SRCLR_5V_BIDI: JP508.1 (A), Q507.3 (D), R515.2
/pads/COL_~SRCLR_OUT: D509.1 (A1), J518.1, JP509.2 (C)
/pads/ROW_VLED: D501.1 (A1), J509.1, J510.1, JP504.2 (C)
GND: C501.2, C502.2, C503.2, C504.2, C505.2, D501.2 (A2), D502.2 (A2), D503.2 (A2), D504.2 (A2), D505.2 (A2), D506.2 (A2), D507.2 (A2), D508.2 (A2), D509.2 (A2), D510.2 (A2), D511.2 (A2), D512.2 (A2), D513.2 (A2), D514.2 (A2), J501.1, J502.1, J519.1, J520.1, Q502.2 (S), Q503.2 (S), Q504.2 (S), Q505.2 (S), Q506.2 (S), R503.2, R504.2, R505.2, R509.2, R511.2; also elsewhere on the board
unnamed: JP503.2 (C), JP507.3 (B)
unnamed: JP504.3 (B), R503.1
unnamed: JP508.2 (C), JP509.3 (B)

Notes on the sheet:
The simple NFET level shifter will work, but is inverting, which precludes reusing ROW_SER/ROW_SRCLR… The bidirectional shifter design is non-inverting, but I'm not sure it will work lol
probably overkill, but would not want all the driver boards to die for a stupid reason and these TVSes are cheap
LedMatrixMux Rev A has a bug which precludes COL_VLED at 5V but COL_VCC at 3V3. Working around on this board by adding 5V signaling option instead of respinning the other one
470u could be too much
clear and disable output by default
rows don't need vled… I think

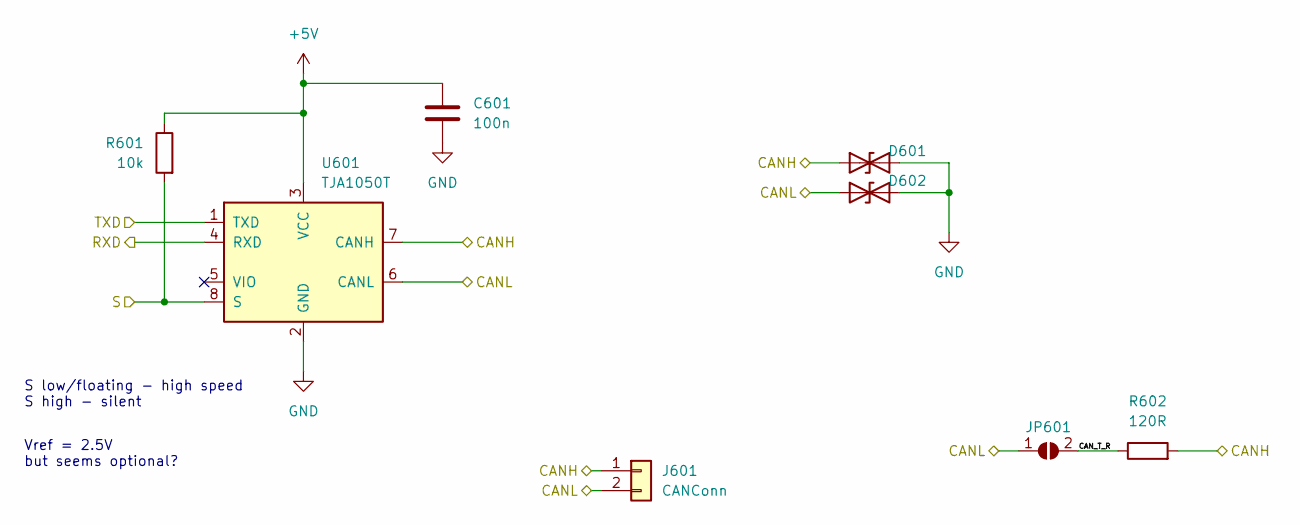
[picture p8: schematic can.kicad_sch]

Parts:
C601: 100n; C_0402_1005Metric; LCSC C1525
D601, D602: H5VL10B; DFN1006_TVS; LCSC C7420372
J601: CANConn; PinHeader_1x02_P2.54mm_Horizontal
JP601: SolderJumper_2_Open; SolderJumper-2_Open_RoundedPad_Smol
R601: 10k; R_0402_1005Metric; LCSC C25744
R602: 120R; R_0402_1005Metric; LCSC C25079
U601: TJA1050T; SOIC-8_3.9x4.9mm_P1.27mm; LCSC C6952

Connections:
+5V: C601.1, R601.1, U601.3 (VCC); also elsewhere on the board
/CAN_RXD: U601.4 (RXD); also elsewhere on the board
/CAN_S: R601.2, U601.8 (S); also elsewhere on the board
/CAN_TXD: U601.1 (TXD); also elsewhere on the board
/can/CANH: D601.1 (A1), J601.1, R602.2, U601.7 (CANH)
/can/CANL: D602.1 (A1), J601.2, JP601.1 (A), U601.6 (CANL)
/can/CAN_T_R: JP601.2 (B), R602.1
GND: C601.2, D601.2 (A2), D602.2 (A2), U601.2 (GND); also elsewhere on the board

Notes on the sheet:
S low/floating - high speed S high - silent
Vref = 2.5V but seems optional?

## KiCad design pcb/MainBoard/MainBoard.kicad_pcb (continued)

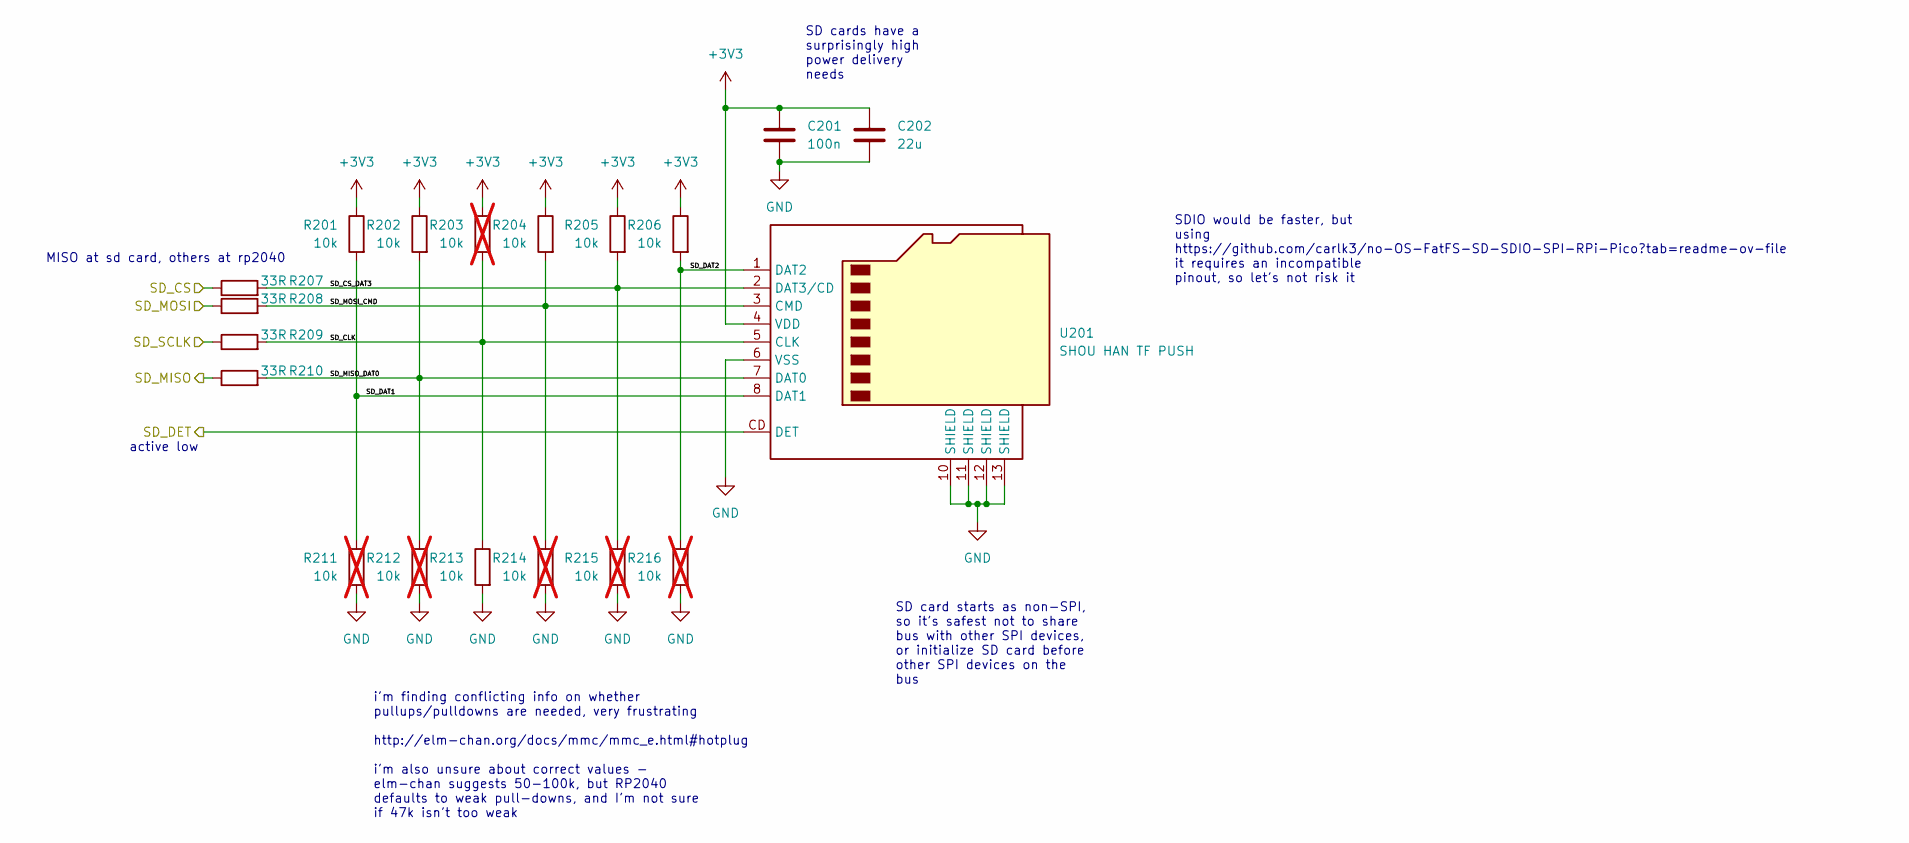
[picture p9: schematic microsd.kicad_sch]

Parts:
C201: 100n; C_0402_1005Metric; LCSC C1525
C202: 22u; C_0805_2012Metric; LCSC C45783
R201, R202, R204, R205, R206, R213: 10k; R_0603_1608Metric; LCSC C25804
R203, R211, R212, R214, R215, R216: 10k; R_0603_1608Metric; LCSC C25804; not fitted
R207, R208, R209, R210: 33R; R_0402_1005Metric; LCSC C25105
U201: SHOU HAN TF PUSH; micro-sd-tf-push; LCSC C393941

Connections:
+3V3: C201.1, C202.1, R201.1, R202.1, R203.1, R204.1, R205.1, R206.1, U201.4 (VDD); also elsewhere on the board
/SD_CS: R207.1; also elsewhere on the board
/SD_DET: U201.CD (DET); also elsewhere on the board
/SD_MISO: R210.1; also elsewhere on the board
/SD_MOSI: R208.1; also elsewhere on the board
/SD_SCLK: R209.1; also elsewhere on the board
/microsd/SD_CLK: R203.2, R209.2, R213.1, U201.5 (CLK)
/microsd/SD_CS_DAT3: R205.2, R207.2, R215.1, U201.2 (DAT3/CD)
/microsd/SD_DAT1: R201.2, R211.1, U201.8 (DAT1)
/microsd/SD_DAT2: R206.2, R216.1, U201.1 (DAT2)
/microsd/SD_MISO_DAT0: R202.2, R210.2, R212.1, U201.7 (DAT0)
/microsd/SD_MOSI_CMD: R204.2, R208.2, R214.1, U201.3 (CMD)
GND: C201.2, C202.2, R211.2, R212.2, R213.2, R214.2, R215.2, R216.2, U201.6 (VSS), U201.10 (SHIELD), U201.11 (SHIELD), U201.12 (SHIELD), U201.13 (SHIELD); also elsewhere on the board

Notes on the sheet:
SD card starts as non-SPI, so it's safest not to share bus with other SPI devices, or initialize SD card before other SPI devices on the bus
i'm finding conflicting info on whether pullups/pulldowns are needed, very frustrating http://elm-chan.org/docs/mmc/mmc_e.html#hotplug i'm also unsure about correct values - elm-chan suggests 50-100k, but RP2040 defaults to weak pull-downs, and I'm not sure if 47k isn't too weak
SD cards have a surprisingly high power delivery needs
SDIO would be faster, but using https://github.com/carlk3/no-OS-FatFS-SD-SDIO-SPI-RPi-Pico?tab=readme-ov-file it requires an incompatible pinout, so let's not risk it
active low
MISO at sd card, others at rp2040

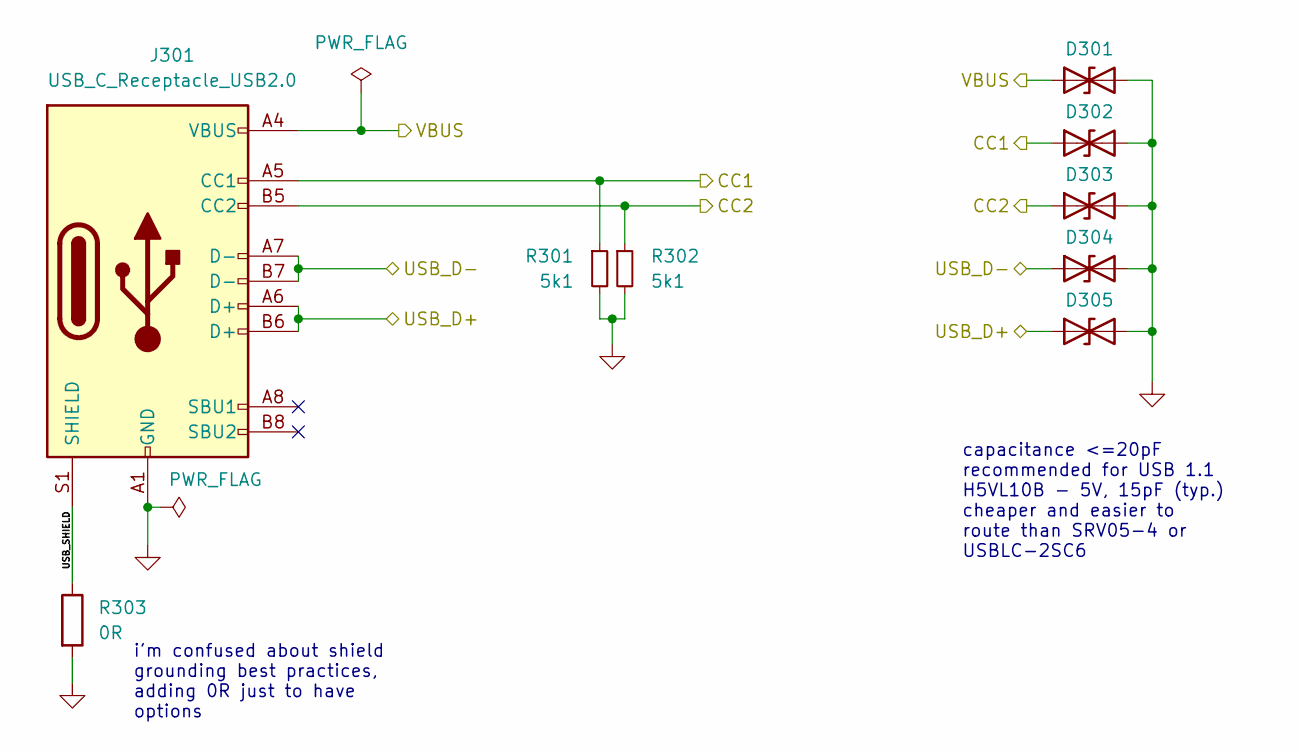
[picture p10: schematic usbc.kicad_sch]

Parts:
D301, D302, D303, D304, D305: H5VL10B; DFN1006_TVS; LCSC C7420372
J301: USB_C_Receptacle_USB2.0; USB_C_Receptacle_HRO_TYPE-C-31-M-12; LCSC C165948
R301, R302: 5k1; R_0402_1005Metric; LCSC C25905
R303: 0R; R_0603_1608Metric; LCSC C21189

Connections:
/CC1: D302.1 (A1), J301.A5 (CC1), R301.1; also elsewhere on the board
/CC2: D303.1 (A1), J301.B5 (CC2), R302.1; also elsewhere on the board
/USB_D+: D305.1 (A1), J301.A6 (D+), J301.B6 (D+); also elsewhere on the board
/USB_D-: D304.1 (A1), J301.A7 (D-), J301.B7 (D-); also elsewhere on the board
/power/VBUS: D301.1 (A1), J301.A4 (VBUS), J301.A9 (VBUS), J301.B4 (VBUS), J301.B9 (VBUS); also elsewhere on the board
/usbc/USB_SHIELD: J301.S1 (SHIELD), R303.1
GND: D301.2 (A2), D302.2 (A2), D303.2 (A2), D304.2 (A2), D305.2 (A2), J301.A1 (GND), J301.A12 (GND), J301.B1 (GND), J301.B12 (GND), R301.2, R302.2, R303.2; also elsewhere on the board

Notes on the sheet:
capacitance <=20pF recommended for USB 1.1 H5VL10B - 5V, 15pF (typ.) cheaper and easier to route than SRV05-4 or USBLC-2SC6
i'm confused about shield grounding best practices, adding 0R just to have options

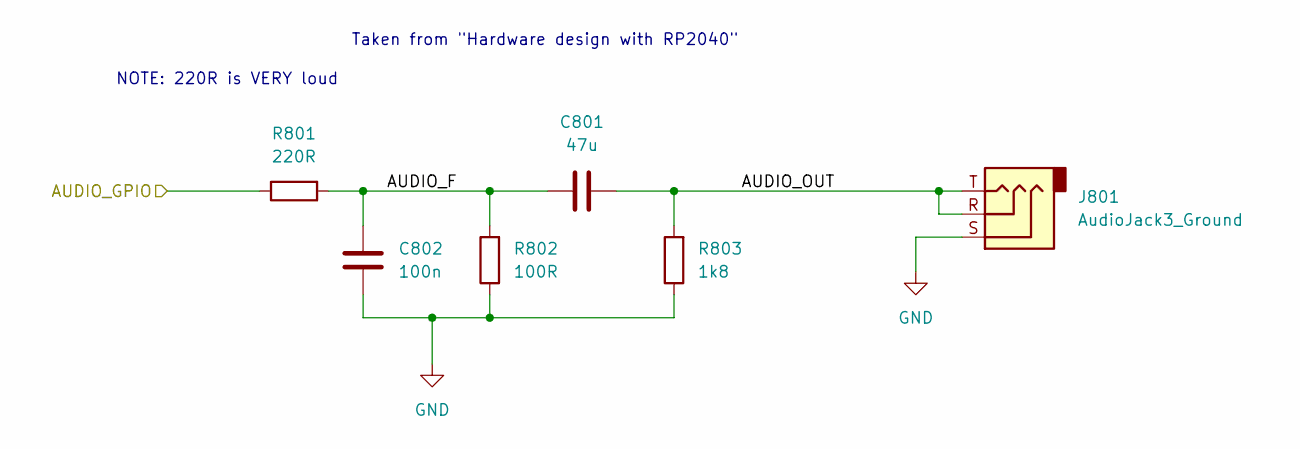
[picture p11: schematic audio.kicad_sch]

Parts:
C801: 47u; C_0805_2012Metric; LCSC C16780
C802: 100n; C_0402_1005Metric; LCSC C1525
J801: AudioJack3_Ground; 3.5mm-audio-jack
R801: 220R; R_0603_1608Metric; LCSC C22962
R802: 100R; R_0402_1005Metric; LCSC C25076
R803: 1k8; R_0603_1608Metric; LCSC C4177

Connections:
/AUDIO_GPIO: R801.1; also elsewhere on the board
/audio/AUDIO_F: C801.1, C802.1, R801.2, R802.2
/audio/AUDIO_OUT: C801.2, J801.R, J801.T, R803.2
GND: C802.2, J801.S, R802.1, R803.1; also elsewhere on the board

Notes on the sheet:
NOTE: 220R is VERY loud
Taken from "Hardware design with RP2040"

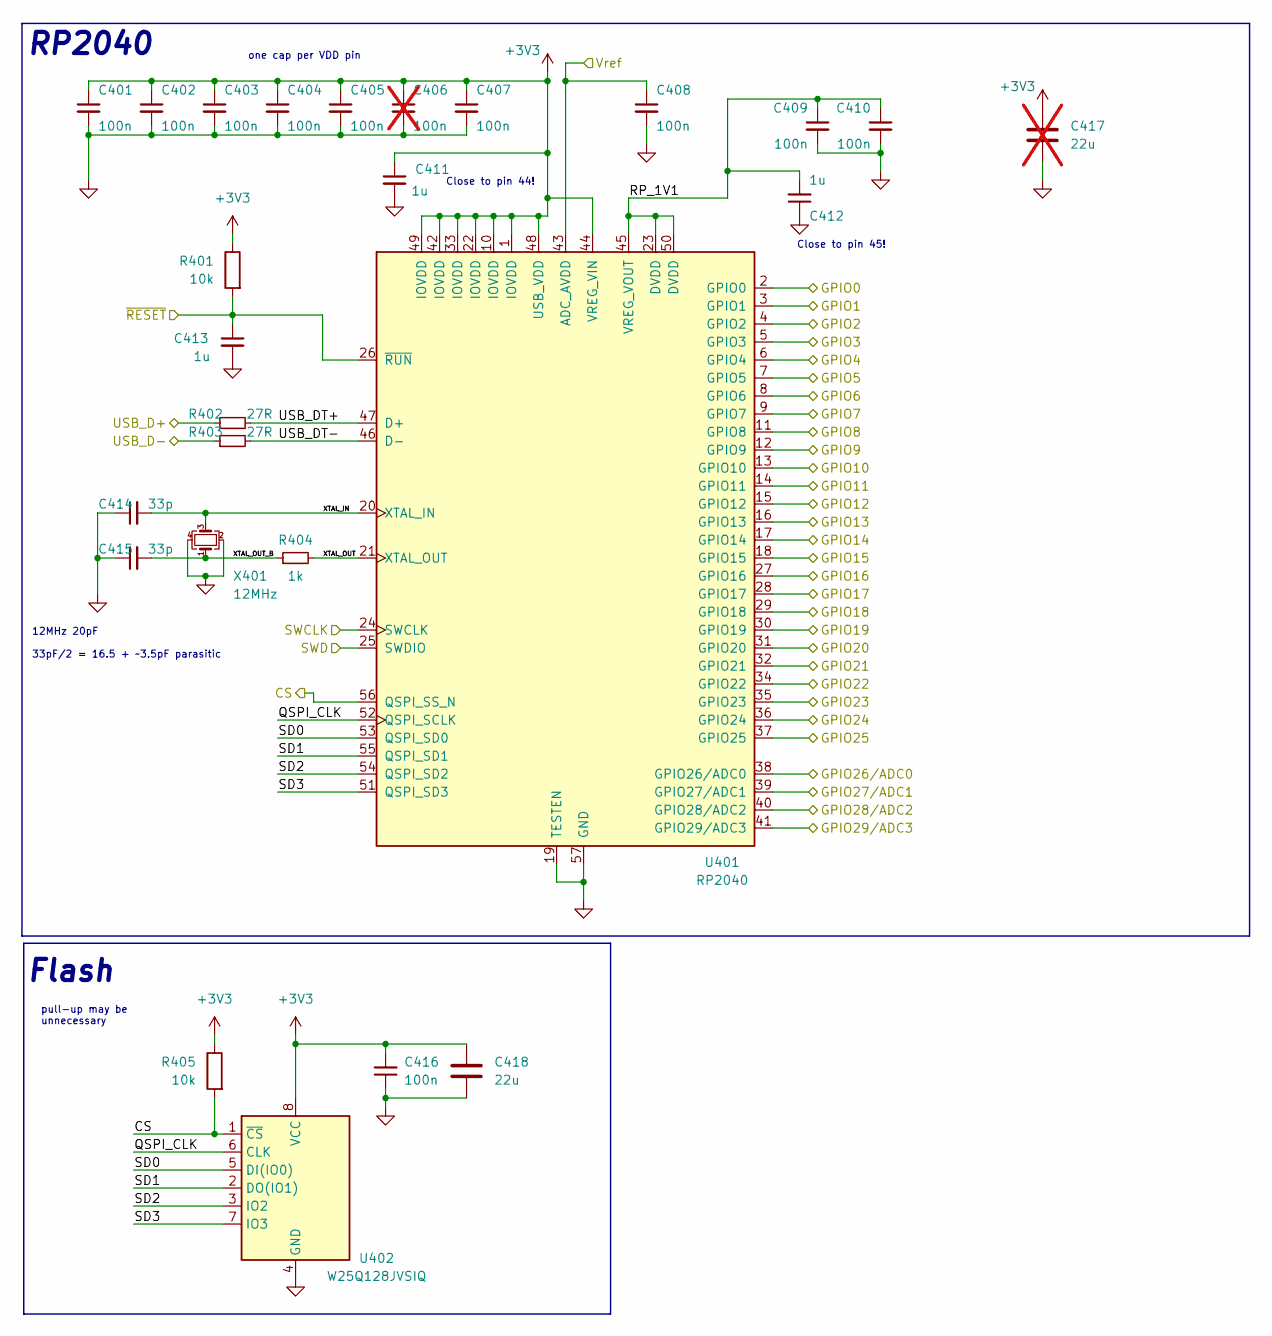
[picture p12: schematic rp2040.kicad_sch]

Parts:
C401, C402, C403, C404, C405, C407, C408, C409, C410, C416: 100n; C_0402_1005Metric; LCSC C1525
C406: 100n; C_0402_1005Metric; LCSC C1525; not fitted
C411, C412, C413: 1u; C_0402_1005Metric; LCSC C52923
C414, C415: 33p; C_0402_1005Metric; LCSC C1570
C417: 22u; C_0805_2012Metric; LCSC C45783; not fitted
C418: 22u; C_0805_2012Metric; LCSC C45783
R401, R405: 10k; R_0402_1005Metric; LCSC C25744
R402, R403: 27R; R_0603_1608Metric; LCSC C25190
R404: 1k; R_0402_1005Metric; LCSC C11702
U401: RP2040; RP2040-QFN-56; LCSC C2040
U402: W25Q128JVSIQ; SOIC-8_5.23x5.23mm_P1.27mm; LCSC C97521
X401: 12MHz; Crystal_SMD_3225-4Pin_3.2x2.5mm; LCSC C9002

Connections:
+3V3: C401.1, C402.1, C403.1, C404.1, C405.1, C406.1, C407.1, C411.1, C416.2, C417.1, C418.1, R401.1, R405.1, U401.1 (IOVDD), U401.10 (IOVDD), U401.22 (IOVDD), U401.33 (IOVDD), U401.42 (IOVDD), U401.44 (VREG_VIN), U401.48 (USB_VDD), U401.49 (IOVDD), U402.8 (VCC); also elsewhere on the board
/5v_sense_F: U401.40 (GPIO28/ADC2); also elsewhere on the board
/AUDIO_GPIO: U401.11 (GPIO8); also elsewhere on the board
/CAN_RXD: U401.7 (GPIO5); also elsewhere on the board
/CAN_S: U401.8 (GPIO6); also elsewhere on the board
/CAN_TXD: U401.9 (GPIO7); also elsewhere on the board
/CC1_F: U401.38 (GPIO26/ADC0); also elsewhere on the board
/CC2_F: U401.39 (GPIO27/ADC1); also elsewhere on the board
/COL_RCLK: U401.35 (GPIO23); also elsewhere on the board
/COL_SER: U401.32 (GPIO21); also elsewhere on the board
/COL_SRCLK: U401.36 (GPIO24); also elsewhere on the board
/COL_~OE: U401.34 (GPIO22); also elsewhere on the board
/COL_~SRCLR: U401.37 (GPIO25); also elsewhere on the board
/CS: R405.2, U401.56 (QSPI_SS_N), U402.1 (~CS); also elsewhere on the board
/GPIO9: U401.12 (GPIO9); also elsewhere on the board
/GPIO10: U401.13 (GPIO10); also elsewhere on the board
/GPIO11: U401.14 (GPIO11); also elsewhere on the board
/GPIO12: U401.15 (GPIO12); also elsewhere on the board
/GPIO13: U401.16 (GPIO13); also elsewhere on the board
/Isense_F: U401.41 (GPIO29/ADC3); also elsewhere on the board
/ROW_RCLK: U401.31 (GPIO20); also elsewhere on the board
/ROW_SER_J: U401.17 (GPIO14); also elsewhere on the board
/ROW_SRCLK: U401.29 (GPIO18); also elsewhere on the board
/ROW_~OE: U401.30 (GPIO19); also elsewhere on the board
/ROW_~SRCLR_J: U401.18 (GPIO15); also elsewhere on the board
/SD_CS: U401.3 (GPIO1); also elsewhere on the board
/SD_DET: U401.6 (GPIO4); also elsewhere on the board
/SD_MISO: U401.2 (GPIO0); also elsewhere on the board
/SD_MOSI: U401.5 (GPIO3); also elsewhere on the board
/SD_SCLK: U401.4 (GPIO2); also elsewhere on the board
/SWCLK: U401.24 (SWCLK); also elsewhere on the board
/SWD: U401.25 (SWDIO); also elsewhere on the board
/UART_RX: U401.28 (GPIO17); also elsewhere on the board
/UART_TX: U401.27 (GPIO16); also elsewhere on the board
/USB_D+: R402.1; also elsewhere on the board
/USB_D-: R403.1; also elsewhere on the board
/rp2040/QSPI_CLK: U401.52 (QSPI_SCLK), U402.6 (CLK)
/rp2040/RP_1V1: C409.1, C410.1, C412.2, U401.23 (DVDD), U401.45 (VREG_VOUT), U401.50 (DVDD)
/rp2040/SD0: U401.53 (QSPI_SD0), U402.5 (DI(IO0))
/rp2040/SD1: U401.55 (QSPI_SD1), U402.2 (DO(IO1))
/rp2040/SD2: U401.54 (QSPI_SD2), U402.3 (IO2)
/rp2040/SD3: U401.51 (QSPI_SD3), U402.7 (IO3)
/rp2040/USB_DT+: R402.2, U401.47 (D+)
/rp2040/USB_DT-: R403.2, U401.46 (D-)
/rp2040/XTAL_IN: C414.2, U401.20 (XTAL_IN), X401.3
/rp2040/XTAL_OUT: R404.2, U401.21 (XTAL_OUT)
/rp2040/XTAL_OUT_B: C415.2, R404.1, X401.1
/~RESET: C413.1, R401.2, U401.26 (~RUN); also elsewhere on the board
GND: C401.2, C402.2, C403.2, C404.2, C405.2, C406.2, C407.2, C408.2, C409.2, C410.2, C411.2, C412.1, C413.2, C414.1, C415.1, C416.1, C417.2, C418.2, U401.19 (TESTEN), U401.57 (GND), U402.4 (GND), X401.2, X401.4; also elsewhere on the board
Vref: C408.1, U401.43 (ADC_AVDD); also elsewhere on the board

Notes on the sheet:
pull-up may be unnecessary
Close to pin 45!
one cap per VDD pin
12MHz 20pF 33pF/2 = 16.5 + ~3.5pF parasitic
Close to pin 44!
RP2040
Flash


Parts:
C701, C702, C711, C712: 4u7; C_0805_2012Metric; LCSC C1779
C703, C706, C708: 22u; C_0805_2012Metric; LCSC C45783
C704: 100u; CP_EIA-3528-15_AVX-H; LCSC C16133; not fitted
C705: 100u; CP_Elec_6.3x7.7
C707: 100n; C_0402_1005Metric; LCSC C1525
C713: 100u; C_1206_3216Metric; LCSC C15008
C714: 100p; C_0402_1005Metric; LCSC C1546
D701, D702: LED; D_0603_1608Metric; LCSC C2986059
F701: 6V 3A 50A 6A; Fuse_1210_3225Metric_Pad1.42x2.65mm_HandSolder; LCSC C2844234
JP701: SolderJumper_3_Open; SolderJumper-3_Open_RoundedPad_Smol
R701: 1k; R_0402_1005Metric; LCSC C11702
R702, R703, R704: 100mΩ; R_1206_3216Metric; LCSC C25334
R705: 1k5; R_0402_1005Metric; LCSC C25867
R706, R710: 470R; R_0603_1608Metric; LCSC C23179
R707, R708: 680R; R_0402_1005Metric; LCSC C25130
R709, R712: 2k; R_0402_1005Metric; LCSC C4109
R711: 5k1; R_0402_1005Metric; LCSC C25905
TP701, TP702, TP703, TP704, TP705, TP707: TestPoint; TestPoint_Pad_D1.0mm
U701: AMS1117-3.3; SOT-223-3_TabPin2; LCSC C6186
U702: INA180A1; SOT-23-5; LCSC C122228
U704: CJ431; SOT-23; LCSC C3113

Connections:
+3V3: C702.1, C703.1, C707.1, C713.1, D701.2, JP701.3 (B), TP701.1, U701.2 (VO), U702.5 (V+); also elsewhere on the board
+5V: C701.1, C711.1, C714.2, D702.2, R701.1, R702.2, R703.2, R704.2, R706.2, TP705.1, U701.3 (VI), U702.4 (-); also elsewhere on the board
/5V_sense: R701.2, R705.1; also elsewhere on the board
/Isense: U702.1; also elsewhere on the board
/power/5V_FILTERED: C714.1, F701.1, R702.1, R703.1, R704.1, TP703.1, TP704.1, U702.3 (+)
/power/VBUS: C704.1, C705.1, C706.1, C708.1, F701.2, TP702.1; also elsewhere on the board
/power/VREF_REF: R707.2, R712.1, U704.2 (REF)
/power/VREF_SHUNT: C712.1, JP701.1 (A), R706.1, R707.1, R711.1, TP707.1, U704.1 (K)
GND: C701.2, C702.2, C703.2, C704.2, C705.2, C706.2, C707.2, C708.2, C711.2, C712.2, C713.2, R705.2, R708.1, R710.1, R711.2, R712.2, U701.1 (GND), U702.2 (GND), U704.3 (A); also elsewhere on the board
unnamed: D701.1, R708.2
unnamed: D702.1, R709.1
unnamed: R709.2, R710.2
Vref: JP701.2 (C); also elsewhere on the board

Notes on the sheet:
smallest jlcpcb basic resistor is 100mΩ. Imax = 3A, R=33mΩ, V=100mV, P=330mW (100mW/resistor)
INA180 allows for measuring higher voltages than supply voltage - so using 3v3 so that input can never be above 3v3
~1mA
5.5V max => 3.3
Vref should ideally be 3v3, 431's reference is 2.5V 3,3*2/2,68=2.46 1,34mA min load: 3,3/5,1=0.6mA (5-3.3)/470=3.6mA



Board: 4 copper layers, 50.0 x 50.0 mm, 198 parts (36 on the bottom side), 97 nets.

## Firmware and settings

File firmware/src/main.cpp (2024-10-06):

#include <Arduino.h>
#include "hardware/gpio.h"
#include "audio.h"
#include "sd.h"
#include "leds.h"
#include "can.h"
#include "gfx_decoder.h"
#include "can2040.h"
#include "config.h"

void loadVideo(size_t index);

void setup() {
  leds_init();
  pinMode(NEXT_PIN, INPUT_PULLUP);

  delay(2000);
  Serial.begin(115200);
  Serial.println("Hello worldd!");

  if (CPU_CLOCK_HZ != rp2040.f_cpu()) {
    Serial.println("CPU clock speed is not set correctly!");
    while (true) {}
  }

  init_audio();
  leds_initRenderer();

  #if CAN_ENABLED
  canbus_setup();
  #endif

  #if SD_HAS_DETECTION
  while (!isSDCardInserted()) {
    Serial.println("SD card not connected, waiting...");
    delay(1000);
  }
  delay(100);
  #endif

  setupSD();
  sd_loadPlaylist();

  #if DEBUG_TEST_FRAME
  gfx_decoder_setTestFrame();
  #else
  loadVideo(0);
  #endif
}

size_t currentVideoIndex = 0;
bool isLoaded = false;

void loadVideo(size_t index) {
  #if DEBUG_TEST_FRAME
  return;
  #endif

  audio_stop();

  sd_loadAudio(index);

  if (!sd_loadGfxFrameLengths(index)) {
    Serial.println("Failed to load gfx frame lengths");
    return;
  }

  if (!sd_loadGfxBlob(index)) {
    Serial.println("Failed to load gfx blob");
    return;
  }

  isLoaded = true;
}

void nextSong() {
  Serial.println("Next song!");
  currentVideoIndex = (currentVideoIndex + 1) % playlistSize;
  loadVideo(currentVideoIndex);
}

void loop() {
  if (digitalRead(NEXT_PIN) == LOW) {
    delay(100);
    nextSong();
    delay(50);
  }

  // if (Serial.available() > 0) {
  //   char c = Serial.read();
  //   if (c == 'p') {
  //     Serial.println("Paused. Press any key to continue.");
  //     leds_disable();
  //     while (Serial.available() == 0) {
  //       Serial.read();
  //       delay(50);
  //     }
  //     Serial.println("Continuing...");
  //   }
  // }

  if (isLoaded) {
    sd_loadNextAudio();

    auto loopStatus = gfx_decoder_handleLoop();

    if (loopStatus == -1) {
      Serial.println("Failed to load frame...");
    } else if (loopStatus == -2) {
      nextSong();
    }
  }

  #if CAN_ENABLED
  auto canbus_status = canbus_loop();
  if (canbus_status.wants_next_song) {
    delay(100);
    nextSong();
    delay(50);
  }
  #endif
}

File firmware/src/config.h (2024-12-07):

#pragma once

#ifndef _config_h
#define _config_h

// --- pinout ---

#define AUDIO_PIN 8

#define SD_PIN_SS 1
#define SD_PIN_SCK 2
#define SD_PIN_MOSI 3
#define SD_PIN_MISO 0
#define SD_HAS_DETECTION true
#define SD_DET_PIN 4

#define CAN_ENABLED true
#define CAN_PIN_RX 5
#define CAN_PIN_TX 7
#define CAN_PIN_SILENT 6

#define UART_TX_PIN 16
#define UART_RX_PIN 17

// NOTE: with current layout, 9-15 are free GPIOs (14, 15 only when using shared SER, SRCLR)
#define NEXT_PIN 9

#define CC1_PIN 26
#define CC2_PIN 27
#define V_SENSE_PIN 28
#define I_SENSE_PIN 29

#if CC1_PIN < 26 || CC1_PIN > 29 || \
    CC2_PIN < 26 || CC2_PIN > 29 || \
    V_SENSE_PIN < 26 || V_SENSE_PIN > 29 || \
    I_SENSE_PIN < 26 || I_SENSE_PIN > 29
#error "Invalid ADC pin"
#endif

// --- pinout - screen ---

// #define COMMON_SER 21
// #define COMMON_RCLK 23
// #define COMMON_SRCLR 25

#define COL_SER 21 // orig: 21
#define COL_OE 22 // orig: 22
#define COL_RCLK 23 // orig: 23
#define COL_SRCLK 24 // orig: 24
#define COL_SRCLR 25 // orig: 25

#define ROW_SER 14
#define ROW_OE 19
#define ROW_RCLK 20
#define ROW_SRCLK 18
#define ROW_SRCLR 15

#define COL_SER_INVERTED true
#define COL_OE_INVERTED false
#define COL_RCLK_INVERTED false
#define COL_SRCLK_INVERTED false
#define COL_SRCLR_INVERTED false

// --- screen settings ---

#define ROW_MODULES 3
#define COL_MODULES 4

#define COLOR_BITS 8

#define MAX_FPS 30
#define MAX_LENGTH_MIN 10

#define ROW_COUNT ROW_MODULES * 20
#define COL_COUNT COL_MODULES * 20

// --- audio settings ---

#define AUDIO_RATE 44000.0f
#define BUFFER_LEN 512*16

// --- other settings ---

#define CPU_CLOCK_HZ 133000000.0f
#define SD_CARD_BAUD_RATE 12 * 1000 * 1000
#define REFERENCE_VOLTAGE 3.3f // for ADC
#define CURRENT_FACTOR 1.0f // for current sensor
#define CAN_BITRATE 500000

// --- debug settings ---

#define DEBUG_TEST_FRAME false
#define DEBUG_FIRST_FRAME false
#define DEBUG_FRAMEBUFFER false

// --- screen - performance ---
// NOTE: In case of screen glitching, these may need to be tweaked to decrease
// data rate to the display and stay within the limits of the hardware/electrical connection
#define LEDS_PIO_CLKDIV 3
// Also see leds.pio where delays may be adjusted (need manual compilation)

// --- screen - color correction ---
// I do not understand color correction, gamma, it's all black magic to me
// This was manually tuned using DEBUG_TEST_FRAME=true test pattern
// See config.cpp
extern uint32_t brightnessPhaseDelays[COLOR_BITS];
extern uint8_t brightnessPhaseDithering[COLOR_BITS];
#define DITHERING_PHASES 20;

#endif

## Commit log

2024-03-18 dump pcbs
    [LedArray.kicad_pcb, LedArray.kicad_sch, LedArrayDemo.kicad_pcb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]
2024-03-23 Revert "noise generation experiments"
    This reverts commit 85142798a8e0810115346d7bb67e7860ed56eca6.
    [main.cpp]
2024-03-23 firmware: decode png frames
2024-03-24 firmware: flip display (not sure why it is decoded flipped)
    [main.cpp]
2024-03-24 failed attempt to do multithreaded png decode
    [main.cpp]
2024-03-24 Revert "failed attempt to do multithreaded png decode"
    This reverts commit 0f517d7d74ee5f2171b8f557d6fbb0bef516ed9e.
    [main.cpp]
2024-03-24 framebuffer, brighter
2024-03-24 pcb: add erratum
2024-03-28 led characterization board test firmware
2024-03-28 Revert "led characterization board test firmware"
    This reverts commit bd8335af0600a93d4246c86012cdbb5c2faacff8.
    [main.cpp]
2024-03-28 uart debug, apply more gamma, parallel processing
2024-04-06 pcb: mux design
    [LedArrayMux.kicad_pcb, LedArrayMux.kicad_sch]
2024-04-13 wip main board pcb
    [MainBoard.kicad_pcb, MainBoard.kicad_sch, audio.kicad_sch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]
2024-04-14 pcb: update errata
2024-04-14 pcb: main board - contd
    [audio.kicad_sch, pads.kicad_sch, power.kicad_sch]
2024-05-16 pwm audio poc
2024-05-16 sd card bullshit
    [audio.kicad_sch, microsd.kicad_sch]
2024-05-17 pcb progress
    [MainBoard.kicad_pcb, MainBoard.kicad_sch, audio.kicad_sch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]
2024-05-17 reading gfx from sd card…
2024-05-18 audio switch lol
2024-05-21 dump pcb
    [MainBoard.kicad_pcb, MainBoard.kicad_sch, can.kicad_sch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]
2024-05-23 MainBoard: fixes, simplify, BOM optimize, DRC fixes, ERC fixes
    [MainBoard.kicad_pcb, MainBoard.kicad_sch, audio.kicad_sch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]
2024-05-24 some pcb review
    [MainBoard.kicad_pcb, power.kicad_sch]
2024-05-25 pcb: fixes, improvements
    [MainBoard.kicad_pcb, MainBoard.kicad_sch, audio.kicad_sch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]
2024-05-26 pcb: add microswitches
    [MainBoard.kicad_pcb, MainBoard.kicad_sch]
2024-05-26 optimize leds stage
2024-05-27 optimize: use PWM interrupt based delays for precision and pipelining
2024-05-27 Revert "wip optimize"
    This reverts commit fa115e88cbc1ec61be11e3de2ae73b7d562d459b.
    [leds.cpp]
2024-05-27 Revert "optimize: use PWM interrupt based delays for precision and pipelining"
    This reverts commit 9f9d089e08edde53dbfe99617f444c4302a76aad.
    [leds.cpp]
2024-06-01 switch to another arduino core?
2024-06-01 add no-OS-FatFS-SD-SDIO-SPI-RPi-Pico-main (wonderful name ain't it)
2024-06-05 leds: fix for new pcb (untested)
    [config.h, leds.cpp]
2024-06-10 pcb: KbdShield (wip)
    [KbdShield.kicad_pcb, KbdShield.kicad_sch]
2024-06-20 pcb/main board: add errata
2024-06-29 leds: make it work (again)
2024-06-30 leds: evolve towards interrupt-friendly rendering
2024-06-30 leds: simplify/optimize render step
2024-10-06 unfinished power code
2024-11-04 LedArrayMux Rev B
    [LedArrayMux.kicad_pcb, LedArrayMux.kicad_sch]
2024-11-04 LedArray Rev B
    [LedArray.kicad_pcb]
2024-12-07 fix load last playlist item
    [sd.cpp]
2024-12-07 fix flipped row and col
    [gfx_decoder.cpp]
2024-12-07 Revert "increase fps to 60"
    This reverts commit 25572a5db91f49c48c6f9a128b5c0efd4455690e.
    [config.h]
